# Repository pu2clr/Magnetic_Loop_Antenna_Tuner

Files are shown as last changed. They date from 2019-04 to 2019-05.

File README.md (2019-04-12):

# Magnetic Loop Antenna controlled by Android and Arduino

[Clique aqui para Documentação em Português](https://github.com/pu2clr/Magnetic_Loop_Antenna_Tuner/tree/master/Documentation)

# Table of contents
1. [Folders structure](https://github.com/pu2clr/Magnetic_Loop_Antenna_Tuner#folders-structure)
2. [Source Code](https://github.com/pu2clr/Magnetic_Loop_Antenna_Tuner#source-code) 
3. [Schematic](https://github.com/pu2clr/Magnetic_Loop_Antenna_Tuner#schematic)
    1. [One capacitor version](https://github.com/pu2clr/Magnetic_Loop_Antenna_Tuner#one-capacitor-version)
    2. [Two capacitor version](https://github.com/pu2clr/Magnetic_Loop_Antenna_Tuner#two-capacitors-version)
4. [The Bluetooth shield used with Arduino](https://github.com/pu2clr/Magnetic_Loop_Antenna_Tuner#the-bluetooth-shield-used-with-arduino)
5. [Arduino prototype](https://github.com/pu2clr/Magnetic_Loop_Antenna_Tuner#arduino-circuit-built-on-protoboard)
   1. [One Capacitor version](https://github.com/pu2clr/Magnetic_Loop_Antenna_Tuner#one-capacitor-version-1)
   2. [Two Capacitor version](https://github.com/pu2clr/Magnetic_Loop_Antenna_Tuner#two-capacitors-version-1)
   3. [Arduino with a HM10 (HMSoft) BLE](/sources/ArduinoBLE#arduino-with--a-hm10-hmsoft-ble)
6. [Android Remote Controll Application](https://github.com/pu2clr/Magnetic_Loop_Antenna_Tuner#android-application)
7. [More about the Android Application and Arduino source code](https://github.com/pu2clr/Magnetic_Loop_Antenna_Tuner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)
8. [Messages received by Arduino via Bluetooth](https://github.com/pu2clr/Magnetic_Loop_Antenna_Tuner#messages-received-by-arduino-via-bluetooth)
9. [Videos](https://github.com/pu2clr/Magnetic_Loop_Antenna_Tuner#videos-about-this-project)
10. [Photos](https://github.com/pu2clr/Magnetic_Loop_Antenna_Tuner#photos)

This project is about a minimalist version of a  Remote Control for Magnetic Loop Antenna controlled by Arduino and Android via Bluetooth. I think it can be improved and adjusted for your needs. 

April 3th, 2019.
By PU2CLR,
Ricardo Lima Caratti..

## Folders structure

- [Box_3D_Printer folder](https://github.com/pu2clr/Magnetic_Loop_Antenna_Tuner/tree/master/Box_3D_Printer) is about a box project to use with this project of antenna tuner on Alexloop Magnetic loop antenna or similar. It can be used to build a tuner box by using a 3D printer. [Click here to see a video that shows the box example project with the Android and Arduino Antenna Tuner](https://youtu.be/OKky8gmOWz8).;
- [images folder](https://github.com/pu2clr/Magnetic_Loop_Antenna_Tuner/tree/master/images) has some pictures about this project
- [schematic folder](https://github.com/pu2clr/Magnetic_Loop_Antenna_Tuner/tree/master/schematic) has the schematic document build by [fritzing software](http://fritzing.org/home/), an open-source hardware initiative that allows us to design electronics circuits;
- [sources folder](https://github.com/pu2clr/Magnetic_Loop_Antenna_Tuner/tree/master/sources) has the Android Magnetic Antenna Tunner Application to control the servo attached to a capacitor via bluetooth connection, and the Arduino sketch that implements the contrrol the capacitor (Servo).

## Source code

All Arduino and Android Application codes are avaiable on [Sources folder](https://github.com/pu2clr/Magnetic_Loop_Antenna_Tuner/tree/master/Sources).  __The bluetooth shield have to be desconected during the sketch upload process__. See [ArduinoOneCapacitor.ino][arduino-one-capacitor], [ArduinoTwoCapacitors.ino][arduino-two-capacitor] and [BluetoothTuner.java][bluetooth-tuner] code documentation. You might need change parameters or adapt it for your needs. There is also a version that use a BLE (Bluetooth Low Energy). Click [here](https://github.com/pu2clr/Magnetic_Loop_Antenna_Tuner/tree/master/sources/ArduinoBLE) to see the BLE version.   

## Schematic 

### One capacitor version 

This setup can be used with Alexloop antenna tuner or similar. The tune and fine tune commands are applied to only one capacitor.

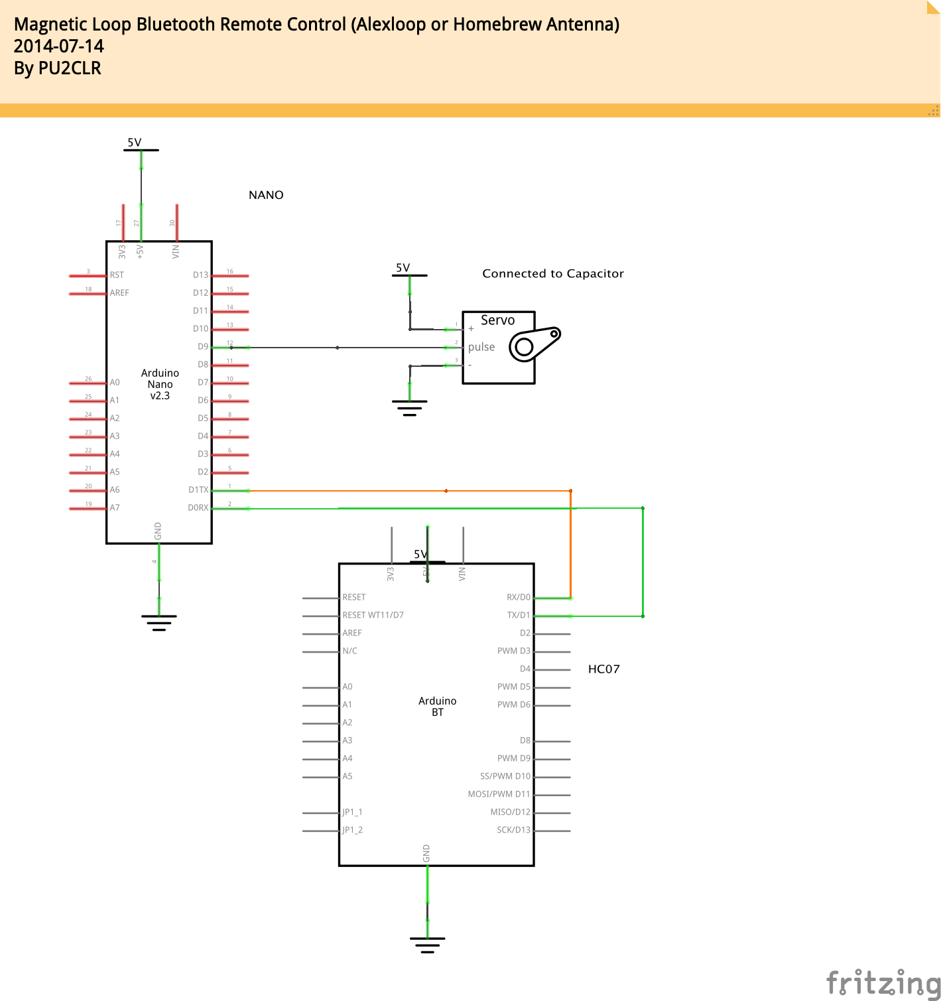
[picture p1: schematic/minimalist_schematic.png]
One capacitor schematic


### Two capacitors version 

This setup uses two servos. The main servo should be attached to a "high" capacitance capacitor. The fine tune servo should be attached to a low capacitance capacitor. This [video](https://youtu.be/w_jXJsiMKIk) shows this idea. 

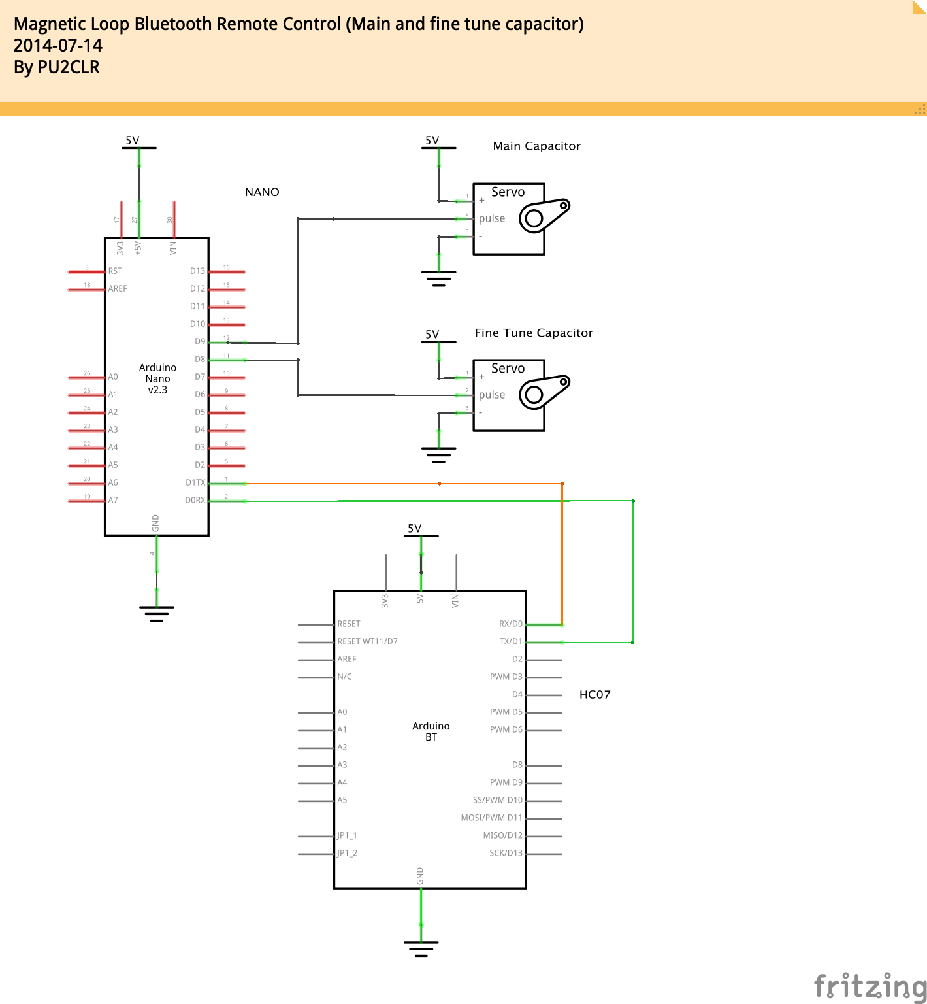
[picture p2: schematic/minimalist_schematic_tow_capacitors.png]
One capacitor schematic


__The same Android Application used to control the One capacitor version can be used to control the two capacitors version.__  There is a checkbox on the Android Application that you can  select one or two capacitors setup. 

__IMPORTANT__:
It is recommended that you check your servo parameters (specifications). You might need change some defined constants on Android Application and Arduino sketch. You will find documentation on [ArduinoOneCapacitor.ino][arduino-one-capacitor], [ArduinoTwoCapacitors.ino][arduino-two-capacitor] and [BluetoothTuner.java][bluetooth-tuner] to do that if necessary.   

## The Bluetooth shield used with Arduino

You can use the HC-05 or HC-07 bluetooth shield. I did not get success with BLE standard and the Android Application developed for this project. 

### Bluetooth HC-05 - Photo 1

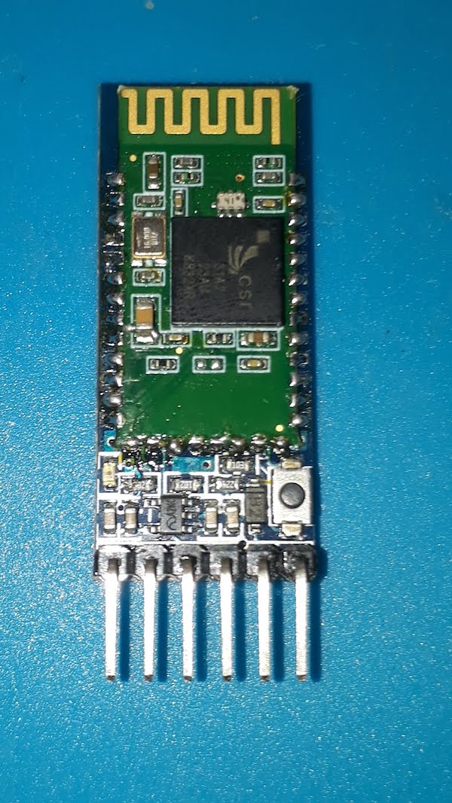
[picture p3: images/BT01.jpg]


### Bluetooth HC-05 - Photo 2

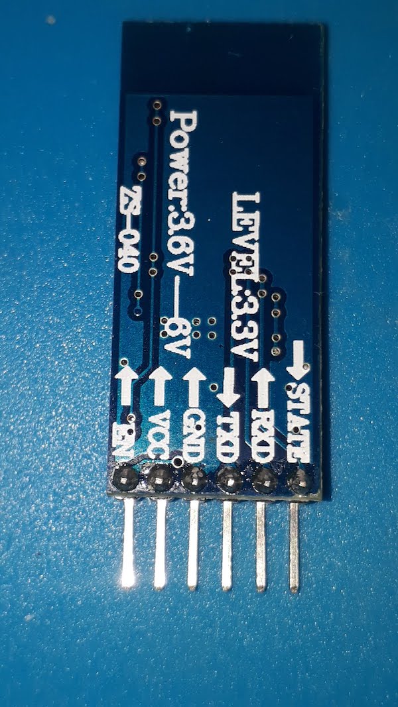
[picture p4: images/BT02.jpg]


### Arduino circuit built on protoboard

#### One Capacitor version

The photo below shows the Android, Bluetooth and Servo setup for one capacitor version. Please, check your Servo specification. You might need to change some definition on the Arduino sketch. See [ArduinoOneCapacitor.ino][arduino-one-capacitor] sketch source code documentation.    

Android Remote Control

#### Two Capacitors version

The photo below shows the Android, Bluetooth and two Servos setup for two capacitors. The fine tune capacitor should have low capacitance. Please, check your Servo specification. You might need to change some definitions on the Arduino sketch. See [ArduinoTwoCapacitor.ino][arduino-two-capacitor] sketch source code documentation.    

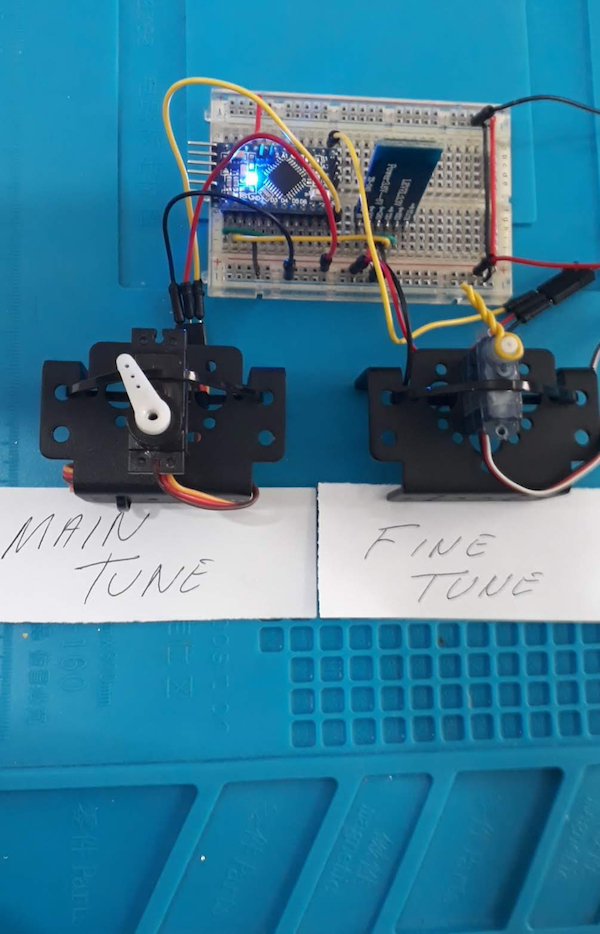
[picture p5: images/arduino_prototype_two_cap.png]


### Android Application 

The version of Android Application used here was built in 2014. The last Android Studio used to build it was 3.3.2 (2019). Probable, you will need to do some adjust on your IDE environment to build this application.

You also might need to check your servo specification and change the [BluetoothTuner.java][bluetooth-tuner] (see comments in the java program). 

#### Android Remote Controll - Photo 1

Connecting to Bluetooth you should press the Bluetooth button and select the paired Bluetooth, in this case it is HC07.  You have to pair the bluetooth before by using system interface. 

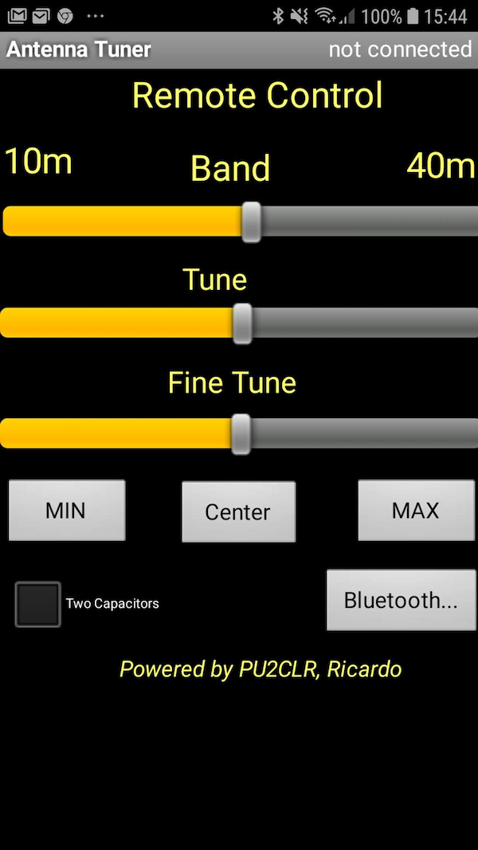
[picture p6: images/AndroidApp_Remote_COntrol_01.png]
Android Remote Control


#### Android Remote Controll - Photo 2

Selecting the paired bluetotth. 

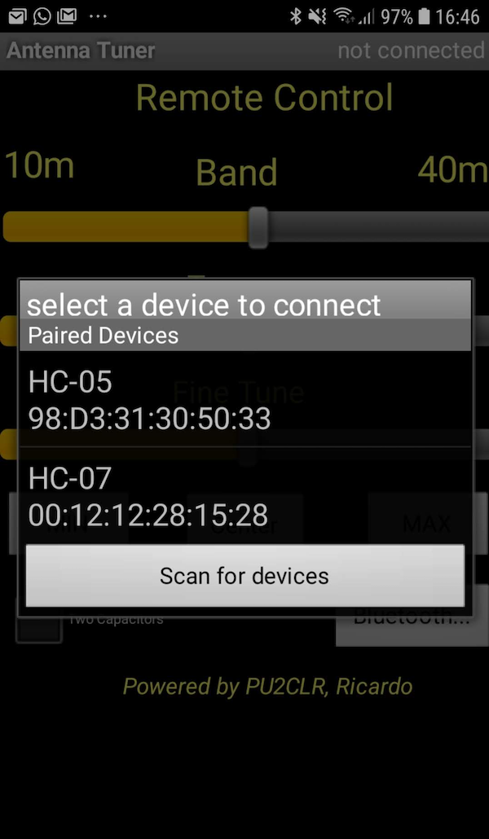
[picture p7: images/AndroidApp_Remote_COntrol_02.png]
Android Remote Control


#### Android Remote Controll - Photo 3

Bluetooth paired and ready to send commands to Arduino circuit.

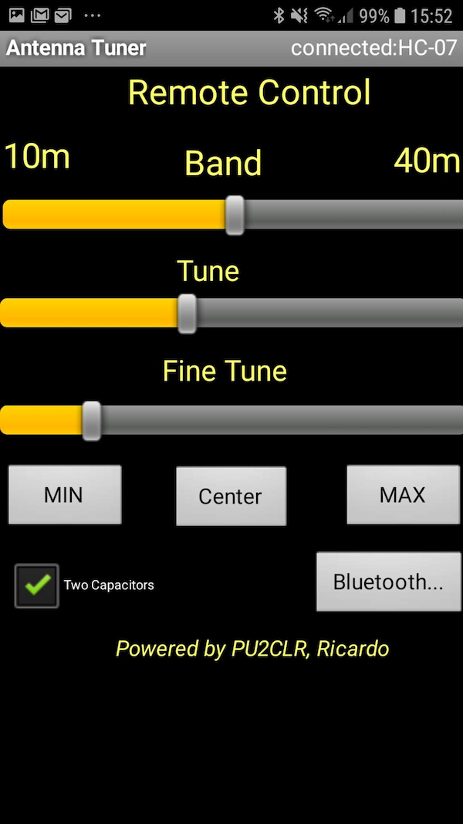
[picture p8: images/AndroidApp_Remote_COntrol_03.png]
Android Remote Control


## More about the Android Application and Arduino source code

All source code can be found [here](https://github.com/pu2clr/Magnetic_Loop_Antenna_Tuner/tree/master/Sources).  You might need to change some configurations depending on servo specification and kind of capacitor you are using. The Arduino and Android Application source code are docummented as shown below.

### Important parts of the Arduino and Android code

The pieces of code below illustrate the configuration on Android Application (Java) and Arduino (C / C ++) that can be adjusted by you according your servo and capacitor specification.

#### Aplicativo Android (BluetoothTuner.java)

```java
    // You might change this setup depending on your servo specification
    public int OFFSET = 800;   // Min. Pisition  (0 degree)
    public int MAXPOS = 2200;  // Max. position  (Max. degrre)
    public int CENTER = (MAXPOS - OFFSET)/2 + OFFSET /2;   // Center is CENTER + OFFSET
```

```java 
    // Change parameters for one or two capacitors
    // You might change the values depending on your capacitance of your capacitor and servo specification
    public void onTwoCapacitorsClicked(View v) {

        boolean chk =((CheckBox) v).isChecked();
        if (chk ) { //
            MIDDLE_MAX_OFFSET = MAXPOS;
            MIDDLE_CENTER = CENTER;
            FINE_MAX_OFFSET = MAXPOS / 4;
            FINE_CENTER = CENTER / 4;
        } else {    // One Capacitor estimated values. You might need change it
            MIDDLE_MAX_OFFSET = MAXPOS / 4;
            MIDDLE_CENTER = CENTER / 4;
            FINE_MAX_OFFSET = MAXPOS / 8;
            FINE_CENTER = CENTER / 8;
        }

        seekbarMiddleTune.setMax(MIDDLE_MAX_OFFSET);
        seekbarMiddleTune.setProgress(MIDDLE_CENTER);

        seekbarFineTune.setMax(FINE_MAX_OFFSET);
        seekbarFineTune.setProgress(FINE_CENTER);

    }
```    

#### Arduino Sketch

```cpp
// Define pulse width modulation for fine, regular and large tune 
#define FINE_TUNE            5            // short pulse on servo
#define NORMAL_TUNE          15           // regular pulse on servo
#define LARGE_TUNE           50           // large pulse on servo

#define SERVO_PIN            9            // Pin where is connected the servo
#define CAP_LED_PIN         13            // Define the status LED pin of the capacitor

#define MIN_PULSE          800          // Min. pulse of the servo (you need to know abour you servo specification)
#define MAX_PULSE         2200          // Max. pulse of the servo (you need to know abour you servo specification)
```

## Messages received by Arduino via Bluetooth

The Arduino receives a message sent by the Android Application or any terminal bluetooth application connect to the Arduino, and proceess this message by sending pulse to the servo attached to the capacitor.  

See on the Arduino sketch (ArduinoOneCapacitor.ino and ArduinoTwoCapacitors.ino), the defined constants FINE_TUNE, NORMAL_TUNE, LARGE_TUNE, MIN_PULSE and MAX_PULSE.  These constants define the pulse width modulation for the servo. You might need to change the values of these constants depending on the servo specification. 

#### Commands received by Arduino via Bluetooth and actions

After the Bluetooth connection is established between Arduino and Android Application, the Arduino start waiting for a message from the remote control. The table below shows the messeges processed by Arduino. 

| Character | Description |
| --- | --- |
| + | Fine tune clockwise (short pulse width modulation). |
| - | Fine tune counter-clockwise (short pulse width modulation). |
| r | Regular tune clockwise (midle pulse width modulation). |
| l | Regular tune counter-clockwise (midle pulse width modulation). |
| R | Large tune clockwise (large pulse width modulation). |
| L | Large tune counter-clockwise (large pulse width modulation). |
| M | The servo goes to the maximum position. |
| m | The servo goes to the minimum position. |
| C or c | The servo goes to central position. |
| F | This means that the servo should go to a certain position. This message is followed by a numeric value (servo position) and the '#' character indicating  the end of the message. Example: The mensagem F1000# makes the servo go to position 1000. | 
| T | Like 'F' this means that the servo should go to a certain position. Example: The mensagem T1500# makes the servo go to position 1500.|

##### IMPORTANT 

The files  [ArduinoOneCapacitor.ino][arduino-one-capacitor], [ArduinoTwoCapacitors.ino][arduino-two-capacitor] and [BluetoothTuner.java][bluetooth-tuner] will help you understand the Antenna Tuner comunication protocol. 

## Photos

### Photo 1 

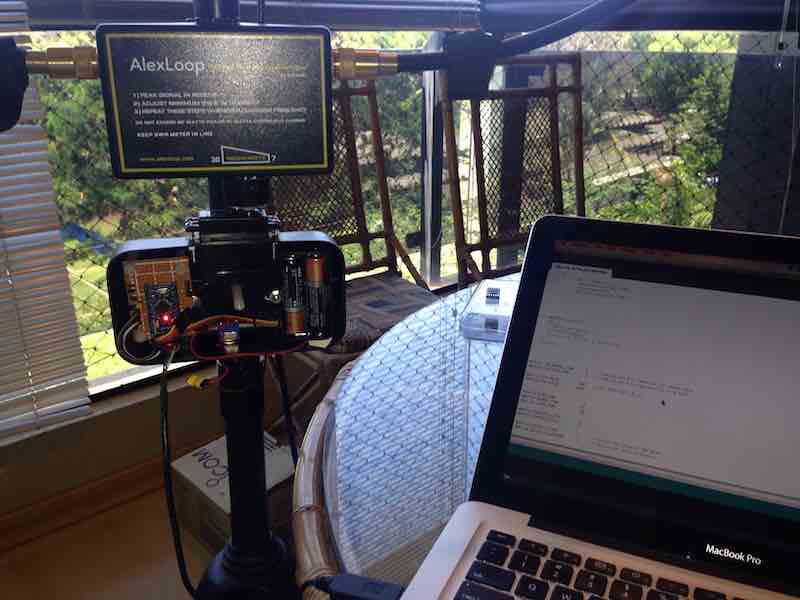
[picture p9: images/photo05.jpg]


### Foto 2

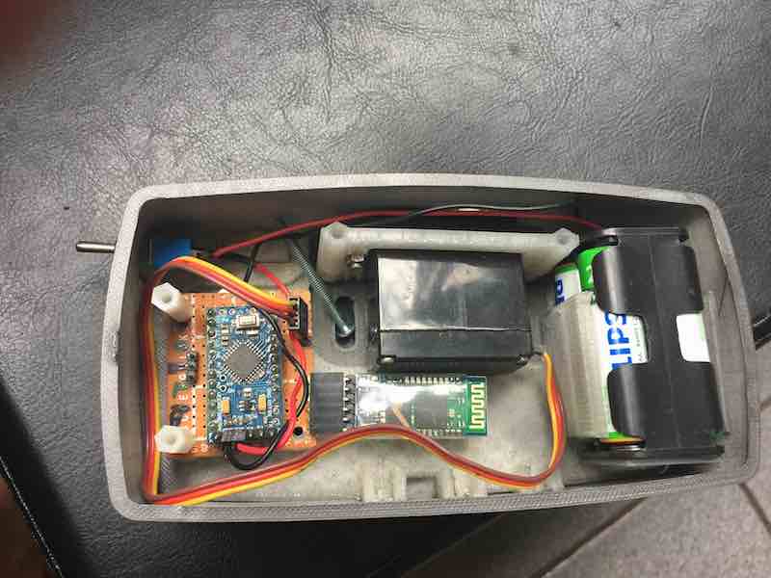
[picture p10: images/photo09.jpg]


### Foto 3

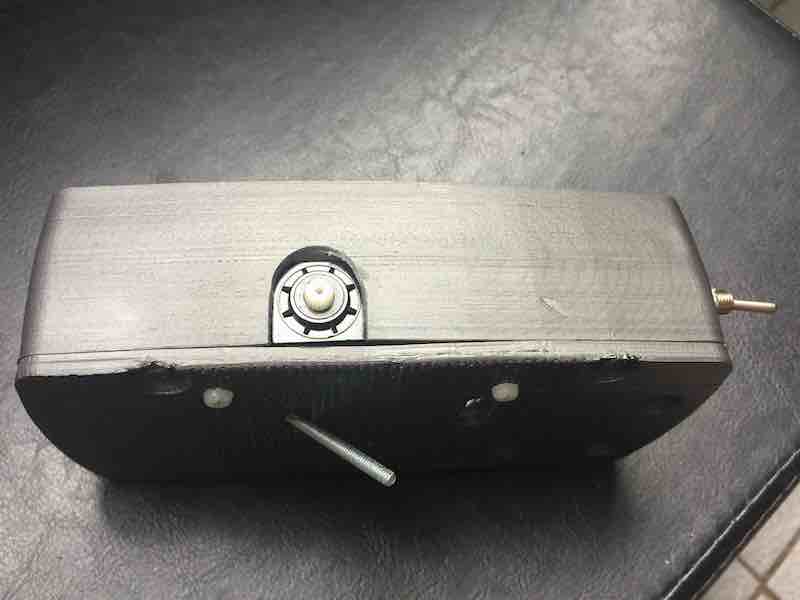
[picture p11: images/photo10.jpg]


## References

- [Arduino](https://www.arduino.cc)
- [App Inventor](http://appinventor.mit.edu/explore/index-2.html)
- [Bluetooth HC-05 specification](https://electrosome.com/hc-05-serial-bluetooth-module/)

## Videos about this project
- [A version of this project working (Youtube Video)](https://youtu.be/PbnP8gIDb78)
- [Remote Tuner for Alexloop (Part I)](https://youtu.be/ZKfOUCcYrz8)
- [Remote Tuner for Alexloop (Part II)](https://youtu.be/PbnP8gIDb78)
- [Antenna Tuner with two capacitors controlled by Arduino](https://youtu.be/Rwl3G2ET7Jw)
- [Antenna Tuner with two capacitors controlled by Arduino - Part II](https://youtu.be/hfnlE1sbnEk)
- [New Android Interface for Antenna Tuner](https://youtu.be/w_jXJsiMKIk)

[//]: References

[arduino-one-capacitor]: <https://github.com/pu2clr/Magnetic_Loop_Antenna_Tuner/blob/master/sources/ArduinoOneCapacitor/ArduinoOneCapacitor.ino>

[arduino-two-capacitor]: <https://github.com/pu2clr/Magnetic_Loop_Antenna_Tuner/blob/master/sources/ArduinoTwoCapacitors/ArduinoTwoCapacitors.ino>

[bluetooth-tuner]: <https://github.com/pu2clr/Magnetic_Loop_Antenna_Tuner/blob/master/sources/AndroidApplication/app/src/main/java/br/eti/caratti/AntennaTuner/BluetoothTuner.java>

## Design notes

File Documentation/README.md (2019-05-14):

# Antena Loop Magnética controlada por SmartPhone Android e Arduino 

# Sumário

1. [Introdução](/Documentation#introdução)
2. [Estrutura de pastas e arquivos](/Documentation#estrutura-de-pastas-e-arquivos)
3. [Como baixar os arquivos deste projeto (Download)](/Documentation#como-baixar-os-arquivos-deste-projeto-download)
4. [Trechos de código sensíveis ao tipo de servo utilizado](/Documentation#trechos-de-código-sens%C3%ADveis-ao-tipo-de-servo-utilizado)
5. [Esquema](/Documentation#esquema-elétrico)
   1. [Com um capacitor](/Documentation#versão-com-um-capacitor)
   2. [Com dois capacitores](/Documentation#versão-com-dois-capacitores)
6. [Dispositivo Bluetooth utilizado neste projeto](/Documentation#dispositivo-bluetooth-utilizado-neste-projeto)
8. [Protótipo Arduino](/Documentation#protótipo-arduino)
   1. [Bluetooth Clássico x BLE](/Documentation#bluetooth-clássico-x-ble)
   2. [Versão com um capacitor (Bluetooth Clássico)](/Documentation#versão-com-um-capacitor)
   3. [Versão com dois capacitores (Bluetooth Clássico)](/Documentation#versão-com-dois-capacitores-1)
7. [Aplicativo Android](/Documentation#aplicativo-android) 
8.  [Código-fonte](/Documentation#código-fonte) 
9. [Protocolo de mensagem (Spartphone e Arduino via Bluetooth)](/Documentation#protocolo-de-mensagem-spartphone-e-arduino-via-bluetooth)
10. [Fotos](/Documentation#fotos)
11. [Videos](https://github.com/pu2clr/Magnetic_Loop_Antenna_Tuner#videos-about-this-project)

## Introdução 

Este projeto é uma versão básica de um Sintonizador de Antenas implementado com Arduino e controlado por um dispositivo móvel baseado em Android. Com este projeto, será possível controlar remotamente, por exemplo, uma Antena Loop Magnética no estilo da [Alexloop](http://www.alexloop.com/index.html) ou uma de construção caseira, via Bluetooth, a partir do seu dispositivo móvel (celular ou tablet) baseado em Android. Há duas opções preferencialmente sugeridas neste documento: uma utilizando o sintonizador de antenas com um capacitor e outra com dois capacitores. Essas duas versões utilizam o Bluetooth Clássico (HC-05, HC-07 etc). __Há também uma versão experimental do sintonizador de antenas utilizando um Bluetooth Low Energy (BLE). No entanto, até o presente momento o aplicativo para celular ainda não foi desenvolvido ou adaptado para esta versão com o BLE__. Assista aos vídeos referenciados no final desta página. Acredito que este projeto possa oferecer os elementos básicos para projetos mais robustos envolvendo as tecnologias utilizadas aqui. 

Fortaleza, 3 de abril de 2019.
Por PU2CLR,
Ricardo Lima Caratti.

## Estrutura de pastas e arquivos

Este trabalho está organizado em pastas. Cada pasta possui o conteúdo descrito a seguir: 

- A pasta [Box_3D_Printer](https://github.com/pu2clr/Magnetic_Loop_Antenna_Tuner/tree/master/Box_3D_Printer) contem o projeto de uma caixa construída em uma impressora 3D especialmente para a [Alexloop][alex-loop] ou similar. [Clique aqui](https://youtu.be/OKky8gmOWz8) para assistir a um vídeo sobre este projeto;
- A pasta [images](https://github.com/pu2clr/Magnetic_Loop_Antenna_Tuner/tree/master/images) contém fotos sobre este projeto;
- A pasta [schematic](https://github.com/pu2clr/Magnetic_Loop_Antenna_Tuner/tree/master/schematic) contém dois esquemas construídos por meio do software  [fritzing](http://fritzing.org/home/), um programa livre para construção de esquemas elétricos. Há duas versões do projeto: uma utilizando um Servo para trabalhar somente com um capacitor; e outra utilizando dois servos para trabalhar com um capacitor principal e outro de sintonia fina;
- A pasta [sources](https://github.com/pu2clr/Magnetic_Loop_Antenna_Tuner/tree/master/sources) contém os códigos-fonte do Aplicativo para SmartPhone para Android,  e dois sketchs (programas para Arduino).  

## Como baixar os arquivos deste projeto (Download)

A estrutura de pastas e arquivos descrita no item anterior é apresentada neste repositório de projetos conforme ilustra a figura a seguir. Clique [aqui](https://github.com/pu2clr/Magnetic_Loop_Antenna_Tuner.git) para entrar na página  e em seguida clique no botão verde, à direita,  identificado por "Clone or Download". 

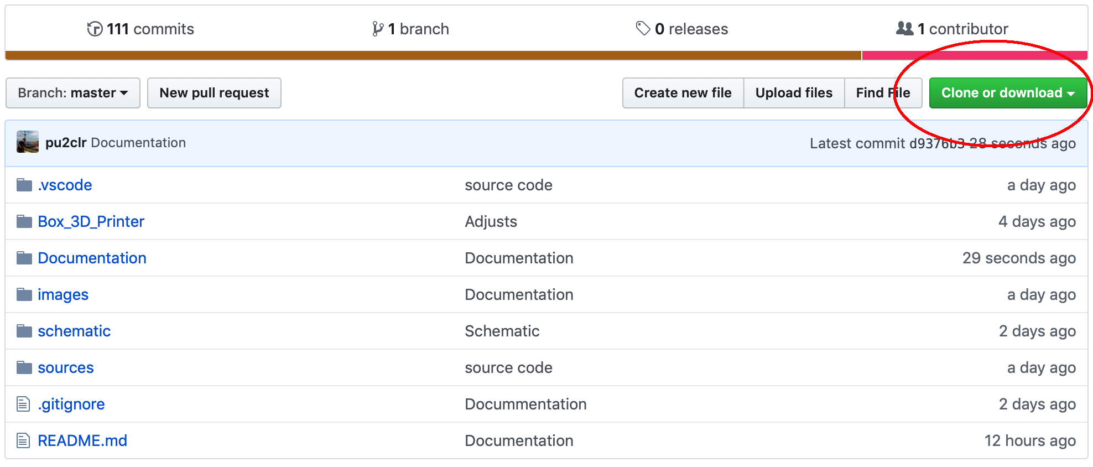
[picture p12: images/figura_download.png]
Página para Download do projeto (https://github.com/pu2clr/Magnetic_Loop_Antenna_Tuner.git/)


## Esquema elétrico

Há duas versões do sintonizador de antena. Uma com um capacitor e outra com dois capacitores. A opção com dois capacitores sugere que o capacitor de sintonia fina seja de baixa capacitância. Dessa forma, o processo de sintonia ficará mais fácil e mais preciso. [Clique aqui](https://youtu.be/w_jXJsiMKIk) para assistir a um vídeo que ilustra o sintonizador com dois capacitores.  

### Versão com um capacitor 

O esquema a seguir ilustra a versão do sintonizador de antena configurado para somente um capacitor acoplado a um servo. Esta versão se aplica para antenas no estilo da [Alexloop][alex-loop] ou loop magnética de construção caseira que utiliza capacitores variáveis com duas ou mais seções.  

One capacitor schematic

### Versão com dois capacitores 

O esquema a segui apresenta a versão do sintonizador com dois capacitores acoplados em dois servos.

One capacitor schematic

### Dispositivo Bluetooth utilizado neste projeto

Os dispositivos HC-05 e HC-06 e HC07 funcionaram com sucesso. A versão utilizando um Bluetooth BLE pode ser vista clicando [aqui](/sources/ArduinoBLE). As figuras a seguir apresentam um bluetooth clássico (HC-05). 

#### Bluetooth Clássico HC-05 - Foto 1
Android Remote Control

#### Bluetooth Clássico HC-05 - Foto 2

Android Remote Control

## Protótipo Arduino

Este projeto apresenta basicamente três opções para a construção de um Sintonizador de Antenas Loop Magnética controlado por Arduino e  Smartphone. A primeira opção propõe a utilização de um capacitor acoplado a um Servo conectado ao Arduino que, por sua vez, interage com um dispositivo Bluetooth clássico (HC-05, HC-07 ou similar). A segunda opção propõe a utilização de dois capacitores, um para sintonia normal e outro para sintonia fina, que operam de forma similar à versão anterior usando um Bluetooth clássico. A terceira opção utiliza praticamente a mesma configuração da primeira opção, exceto que no lugar do Bluetooth Clássico, é utilizado um BLE (HM10 / HMSoft). Os códigos para cada opção descrita anteriormente estão disponíveis na pasta [sources deste repositório](https://github.com/pu2clr/Magnetic_Loop_Antenna_Tuner/tree/master/sources).

As duas primeiras opção funcionam perfeitamente em dispositivos móveis Android (Celular ou Tablet) por meio do [Aplicativo Android](/Documentation#aplicativo-android) desenvolvido para este projeto. Isto é, com o mesmo Aplicativo Android, é possível controlar um sintonizador de antena loop magnética com um ou dois capacitores usando o __Bluetooth Clássico__.

A terceira opção deste projeto implementa a comunicação do Arduino com BLE. No entanto, até o momento em que escrevo estas linhas, ainda não desenvolvi um programa específico para controlar remotamente o sintonizador de antenas via BLE. É possível porém, utilizar um Aplicativo qualquer de comunicação serial para este fim. Clique [aqui](https://github.com/pu2clr/Magnetic_Loop_Antenna_Tuner/tree/master/sources/ArduinoBLE) para mais detalhes sobre como controlar o sintonizador de antenas loop magnética usando BLE. 

### Bluetooth Clássico x BLE

Inicialmente, o sintonizador remoto para antena loop magnética usando Smartphone via Bluetooth, foi projetado para funcionar com  dispositivos Bluetooth clássicos do tipo HC-05, HC-7 etc. No entanto, nos últimos 5 anos, a oferta de dispositivos Bluetooth com a especificação BLE (Bluetooth Low Energy) para plataformas de desenvolvimento como Arduino aumentou sobremaneira. Além disso, o custo destes dispositivos Bluetooth ficou bastante atrativo. Seguem algumas considerações e experiências sobre os dois tipos de Bluetooth observadas durante o desenvolvimento deste projeto:

- O Bluetooth Clássico oferece uma documentação mais rica e com mais exemplos e experiências de uso em projetos com Arduino
- Os dispositivos Bluetooth clássicos ainda são mais baratos e mais fáceis de serem adquiridos; 
- BLE permite conexão com dispositivos móveis da linha Apple. Com isso, é possível desenvolver ou obter um aplicativo de terceiro para iOS que possa ser utilizado com o sintonizador de antenas proposto neste projeto;
- Ainda que seja possível utilizar este projeto em ambiente iOS via BLE, o Bluetooth não aparece na lista padrão de dispositivos pareados do sistema da Apple. Ou seja, o BLE só é visualizado durante a execução do Aplicativo utilizado como controle remoto. Este comportamento pode confundir o usuário em sua primeira análise;
- Em dispositivos do tipo Android, o BLE funciona quase da mesma forma que o Bluetooth Clássico. Isto é, não há diferença visível para o usuário final entre o modelo clássico e o BLE. 
- No que tange à codificação de programas usando Bluetooth Clássico e BLE, tanto programa Arduino (sketch) como o programa para dispositivos móveis Android e iOS utilizam abordagens diferentes. Isto é, uma vez selecionado o tipo de Bluetooth que será utilizado, o código desenvolvido deve utilizar as blbliotecas e APIs (Application Program Interface) contruídas para o Bluetooth escolhido.   

## Propostas para construção do sintonizador de Antenas Controlado por Arduino e Smartphone

### Versão com um Capacitor

A foto a seguir mostra a configuração do  Android, Bluetooth __Clássico (HC-05, HC-07 etc)__ e Servo. É recomendável que você verifique as especificações do servo que você estiver utilizado. É possível que você necessite alterar  algumas definições do servo no sketch.  Tente acompanhar a documentação existente no próprio sketch.

Android Remote Control

### Versão com dois capacitores

A foto a seguir apresenta a montagem da versão do protótipo utilizando dois servos que serão acoplados a dois capacitores. 
O sketch [ArduinoTwoCapacitor.ino][arduino-two-capacitor] implementa este versão.    

Android Remote Control

## Aplicativo Android

A aplicação para dispositivo Android foi desenvolvido em 2014 utilizando os recursos nativos do ambiente de desenvolvimento para Android (conhecido atualmente como Android Studio). A última compilação deste aplicativo foi em 2019 utilizando o [Android Studio 3.3.2.](https://developer.android.com/studio/). O programa está bem documentado e poderá ajudá-lo a entender como foi feita a comunicação de um dispositivo Android com o Arduino via Bluetooth Clássico. O módulo principal do aplicativo é o [BluetoothTuner.java][bluetooth-tuner].  Baixe e instale o [Android Studio](https://developer.android.com/studio/) e __siga as orientações do ambiente de desenvolvimento Android para abrir, compilar e instalar o aplicativo no seu dispositivo móvel__. 

Atualmente há outros ambientes de desenvolvimento para Android mais fácies de utilizar e desenvolver esse tipo de aplicativo. Recomendo fortemente a utilização do [MIT App Inventor](http://appinventor.mit.edu/explore/index-2.html). Veja também outros ambientes de desenvolvimento multiplataforma como [Apache Cordova](https://cordova.apache.org) e [Ionic](https://ionicframework.com). 

### Foto 1

A figura a seguir ilustra a primeira tela do aplicativo. Você precisará parear o Bluetooth previamente em seu dispositivo móvel (celular ou tablet). 

Android Remote Control

### Foto 2

Na lista de dispositivos Bluetooth pareados, selecione o Bluetooth conectado ao Arduino (foi usando nos testes o HC-05, HC-06 e HC-07). 

Android Remote Control

### Foto 3

Uma vez conectado o Bluetooth com sucesso, o Aplicativo pode ser utilizado para enviar comandos para o Arduino.

Android Remote Control

### Código-fonte

Todos os fontes utilizados neste projeto estão disponíveis na [pasta 'sources'](https://github.com/pu2clr/Magnetic_Loop_Antenna_Tuner/tree/master/Sources).  __Durante o upload do sketch para o Arduino, você deve desconectar o Bluetooth do arduino__. É recomendável acompanhar a documentação escrita no programa.

Dependendo da configuração que você optar, um ou dois capacitores, bem como as especificações técnicas do servo que você utiliza, é possível que você precise modificar alguns parâmetros no sketch do Arduino e também no Aplicativo Android. 
Veja a documentação nos fontes [ArduinoOneCapacitor.ino][arduino-one-capacitor], [ArduinoTwoCapacitors.ino][arduino-two-capacitor] e [BluetoothTuner.java][bluetooth-tuner]. 

### Trechos de código sensíveis ao tipo de servo utilizado

Os trechos de código a seguir ilustram a configuração no Aplicativo Android  (em Java) e Arduino (em C/C++) que permitem um ajuste fino do servo e capacitor utilizado por você. Caso não conheça os valores especificados pelo seu servo, inicie seus testes sem fazer alteração nos códigos

#### Trechos no Aplicativo Android (BluetoothTuner.java)

É nenessário um conhecimento mínimo em desenvolvimento de aplictivos para Android para elaborar algumas mudanças no Aplicativo. Caso você não se sinta seguro para fazer isso, é melhor iniciar os experimentos sem fazer alteração alguma. 

O código a seguir define os limites máximo (MAXPOS) e mínimo (OFFSET), bem como a posição central (CENTER) do servo no Aplicativo Android ([BluetoothTuner.java][bluetooth-tuner]). Os componentes de interface do aplicativo __SeekBar__ (barras Band, Tune e Fine Tune) utilizam estes valores como referência para enviar valores entre os limites (MAXPOS e OFFSET) para o servo na proporção que o usuário do aplicativo arrasta o dedo sobre os componentes de interface. 

```java
    // You might change this setup depending of your servo specification
    public int OFFSET = 800;   // Min. Pisition  (0 degree)
    public int MAXPOS = 2200;  // Max. position  (Max. degrre)
    public int CENTER = (MAXPOS - OFFSET)/2 + OFFSET /2;   // Center is CENTER + OFFSET
```

O código a seguir configura a sintonia fina (Tune e Fine Tune) e usa como referência as constantes descritas anteriormente. Note também que, dependendo da configuração selecionada (um ou dois capacitores), os valores para componentes de sintonia fina mudam. É possível que você encontre valores mais adequados para o seu tipo de servo e capacitância do seu capacitor.

```java 
    // Change parameters for one or two capacitors
    // You might change the values depending of your capacitance of your capacitor and servo specification
    public void onTwoCapacitorsClicked(View v) {

        boolean chk =((CheckBox) v).isChecked();
        if (chk ) { //
            MIDDLE_MAX_OFFSET = MAXPOS;
            MIDDLE_CENTER = CENTER;
            FINE_MAX_OFFSET = MAXPOS / 4;
            FINE_CENTER = CENTER / 4;
        } else {    // One Capacitor estimated values. You might need change it
            MIDDLE_MAX_OFFSET = MAXPOS / 4;
            MIDDLE_CENTER = CENTER / 4;
            FINE_MAX_OFFSET = MAXPOS / 8;
            FINE_CENTER = CENTER / 8;
        }

        seekbarMiddleTune.setMax(MIDDLE_MAX_OFFSET);
        seekbarMiddleTune.setProgress(MIDDLE_CENTER);

        seekbarFineTune.setMax(FINE_MAX_OFFSET);
        seekbarFineTune.setProgress(FINE_CENTER);

    }
```    

#### Trechos no sketch (Android)

O código a seguir definem os valores máximos (MAX_PULSE) e mínimos (MIN_PULSE) dos servos no programa Arduino. Também define as constantes de sintonia fina (FINE_TUNE), sintonia (NORMAL_TUNE) e banda (LARGE_TUNE) que __não__ são utilizadas no caso do aplicativo Android. O Aplicativo Android já envia o valor exato da posição do servo.

```cpp
// Define pulse width modulation for fine, regular and large tune 
#define FINE_TUNE            5            // short pulse on servo
#define NORMAL_TUNE          15           // regular pulse on servo
#define LARGE_TUNE           50           // large pulse on servo

#define SERVO_PIN            9            // Pin where is connected the servo
#define CAP_LED_PIN         13            // Define the status LED pin of the capacitor

#define MIN_PULSE          800          // Min. pulse of the servo (you need to know abour you servo specification)
#define MAX_PULSE         2200          // Max. pulse of the servo (you need to know abour you servo specification)
```

## Protocolo de mensagem (Spartphone e Arduino via Bluetooth)

O Arduino recebe as mensagens enviadas pelo Aplicativo Android via conexão [UART](https://paginas.fe.up.pt/~hsm/docencia/comp/uart/). Qualquer programa que utiliza Bluetooth e for capaz de enviar sequências de caracteres poderá ser utilizado. A tabela a seguir apresenta os comandos (mensagens) e as ações executadas pelo Arduino.   

Para mais informações, veja no sketch Arduino ([ArduinoOneCapacitor.ino][arduino-one-capacitor] ou [ArduinoTwoCapacitors.ino][arduino-two-capacitor]), as constantes definidas FINE_TUNE, NORMAL_TUNE, LARGE_TUNE, MIN_PULSE and MAX_PULSE.  Estas constantes definem a largura de pulso para rodar o servo vendidos. Embora a maioria dos servos encontrados no comércio utilizem especificações similares, é possível que você precise modificar os valores para adequar melhor ao seu servo. O condigo-fonte [BluetoothTuner.java][bluetooth-tuner] (do aplicativo Android) também pode precisar de ajustes dependendo do seu servo. 

### Tabela de comandos recebidos pelo Arduino via Bluetooth

| Mensagem | Descrição |
| --- | --- |
| + | Sintonia fina no sentido horário. |
| - | Sintonia fina no sentido anti-horário. |
| r | Sintonia média no sentido horário. |
| l | Sintonia média no sentido anti-horário. |
| R | Sintonia larga no sentido horário. |
| L | Sintonia larga no sentido anti-horário. |
| M | Faz com que o servo ou servos girem até a posição máxima. |
| m | Faz com que o servo  ou servos girem até a posição mínima. |
| C or c | Posiciona o servo ou servos no centro. |
| F | Esta mensagem vem composta com número e conduz o servo para uma posição específica. Exemplo: a mensagem F1000# faz com que o servo vá para a posição 1000. O caractere # indica o fim da mensagem para este caso. | 
| T | Como descrito em  anteriormente ('F') este mensagem conduz o servo para ir para uma dada posição. Exemplo: a mensagem  T1500# faz com que o servo vá para a posição 1500.|

#### IMPORTANTE 

Os arquivos (código-fonte) [ArduinoOneCapacitor.ino][arduino-one-capacitor], [ArduinoTwoCapacitors.ino][arduino-two-capacitor] and [BluetoothTuner.java][bluetooth-tuner] poderão ser úteis para o entendimento deste protocolo de comunicação.

# Fotos

### Foto 4

Android Remote Control

### Foto 5

Android Remote Control

### Foto 6

Android Remote Control

## Referências

- [Arduino](https://www.arduino.cc)
- [App Inventor](http://appinventor.mit.edu/explore/index-2.html)
- [Bluetooth HC-05 specification](https://electrosome.com/hc-05-serial-bluetooth-module/)

## Vídeos

- [Sobre a versão deste projeto no Youtube](https://youtu.be/PbnP8gIDb78)
- [Remote Tuner for Alexloop (Part I)](https://youtu.be/ZKfOUCcYrz8)
- [Remote Tuner for Alexloop (Part II)](https://youtu.be/PbnP8gIDb78)
- [Antenna Tuner with two capacitors controlled by Arduino](https://youtu.be/Rwl3G2ET7Jw)
- [Antenna Tuner with two capacitors controlled by Arduino - Part II](https://youtu.be/hfnlE1sbnEk)
- [New Android Interface for Antenna Tuner](https://youtu.be/w_jXJsiMKIk)

[//]: References

[arduino-one-capacitor]: <https://github.com/pu2clr/Magnetic_Loop_Antenna_Tuner/blob/master/sources/ArduinoOneCapacitor/ArduinoOneCapacitor.ino>

[arduino-two-capacitor]: <https://github.com/pu2clr/Magnetic_Loop_Antenna_Tuner/blob/master/sources/ArduinoTwoCapacitors/ArduinoTwoCapacitors.ino>

[bluetooth-tuner]: <https://github.com/pu2clr/Magnetic_Loop_Antenna_Tuner/blob/master/sources/AndroidApplication/app/src/main/java/br/eti/caratti/AntennaTuner/BluetoothTuner.java>

[alex-loop]: <http://www.alexloop.com>

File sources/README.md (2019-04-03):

#  Arduino and Android Application codes

All Arduino and Android Application codes are avaiable here.  

## Android Application

If you want to use the Android Application without any modification, you can install the binary located at __AndroidApplication/app/build/outputs/apk/debug/__ folder ([click here to download the apk](https://github.com/pu2clr/Magnetic_Loop_Antenna_Tuner/blob/master/sources/AndroidApplication/app/build/outputs/apk/debug/app-debug.apk)).  However, it is recomended to use the [Android Studio](https://developer.android.com/studio) to modify, build and deploy the aplication.

## Arduino Sketch

The [ArduinoOneCapacitor folder](https://github.com/pu2clr/Magnetic_Loop_Antenna_Tuner/tree/master/sources/ArduinoOneCapacitor) has the [Arduino sketch](https://github.com/pu2clr/Magnetic_Loop_Antenna_Tuner/blob/master/sources/ArduinoOneCapacitor/ArduinoOneCapacitor.ino). 

The sketch is documented and can help you to understand the protocol used to communicate with Android Device. Please, Dropout (disconnect) the Bluetooth from Arduino to upload this sketch to Arduino. After upload, connect again the Bluetooth to Arduino. 

__The bluetooth shield have to be desconected during the sketch upload process__. 

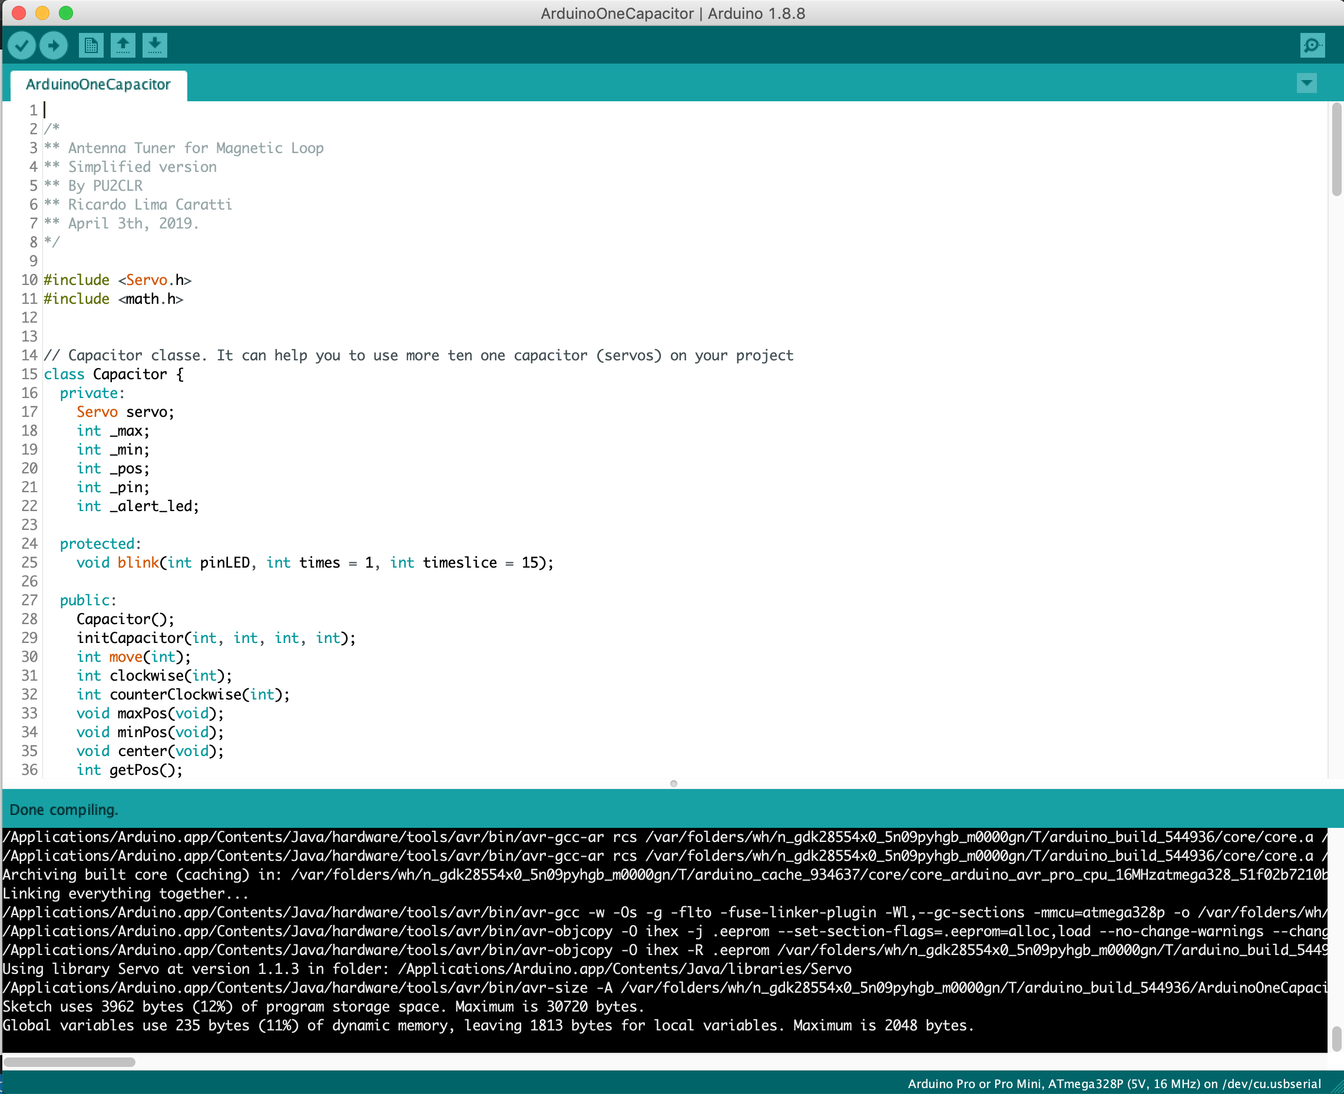
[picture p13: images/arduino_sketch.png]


## Android Studio 

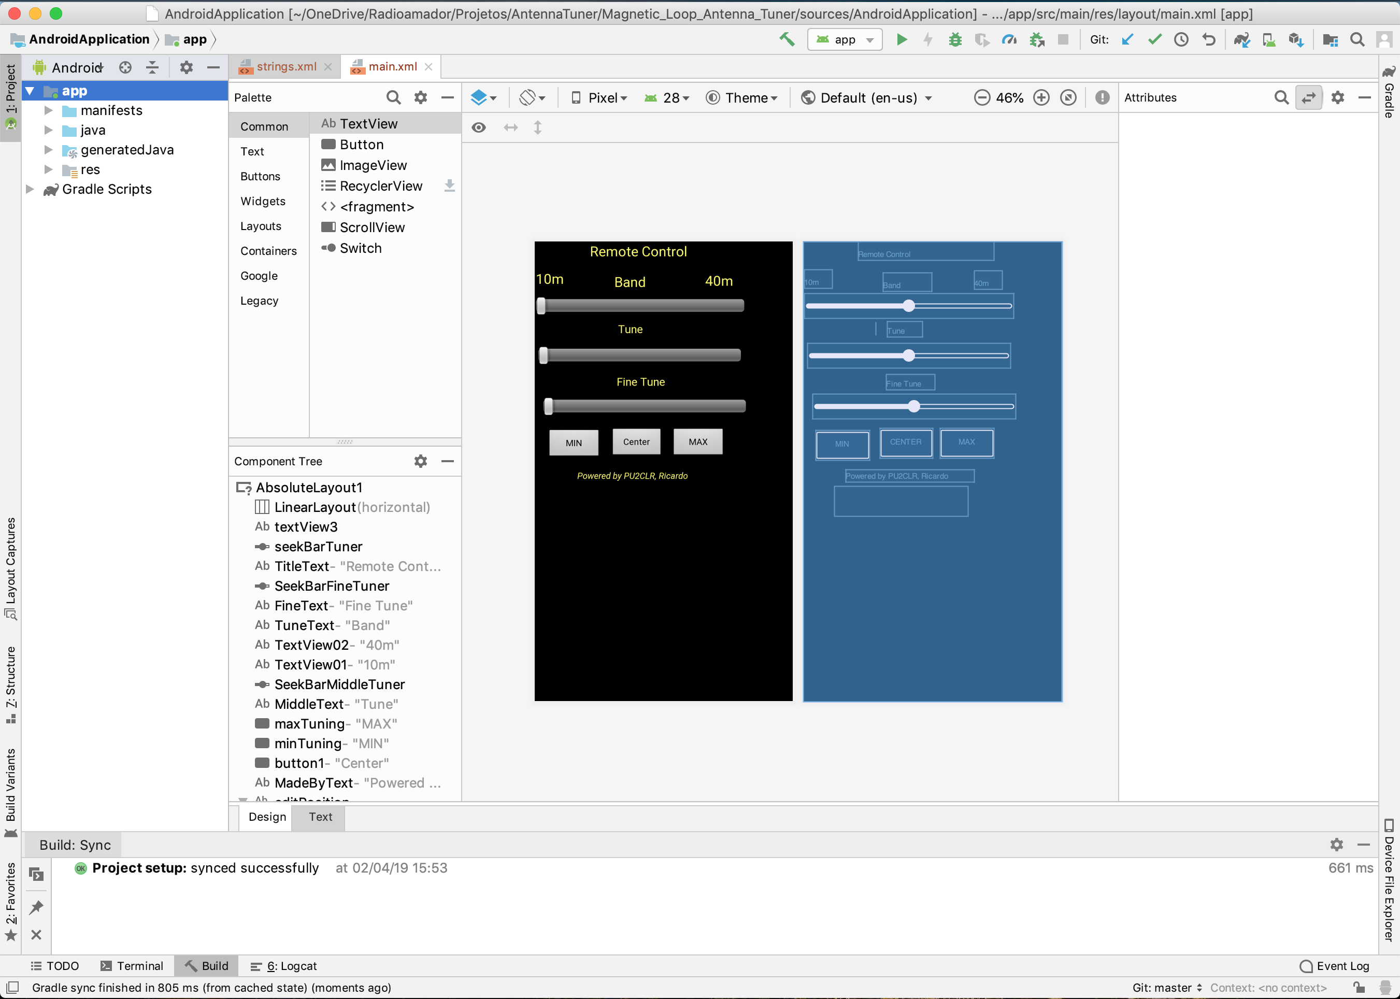
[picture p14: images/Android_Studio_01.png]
Android Studio


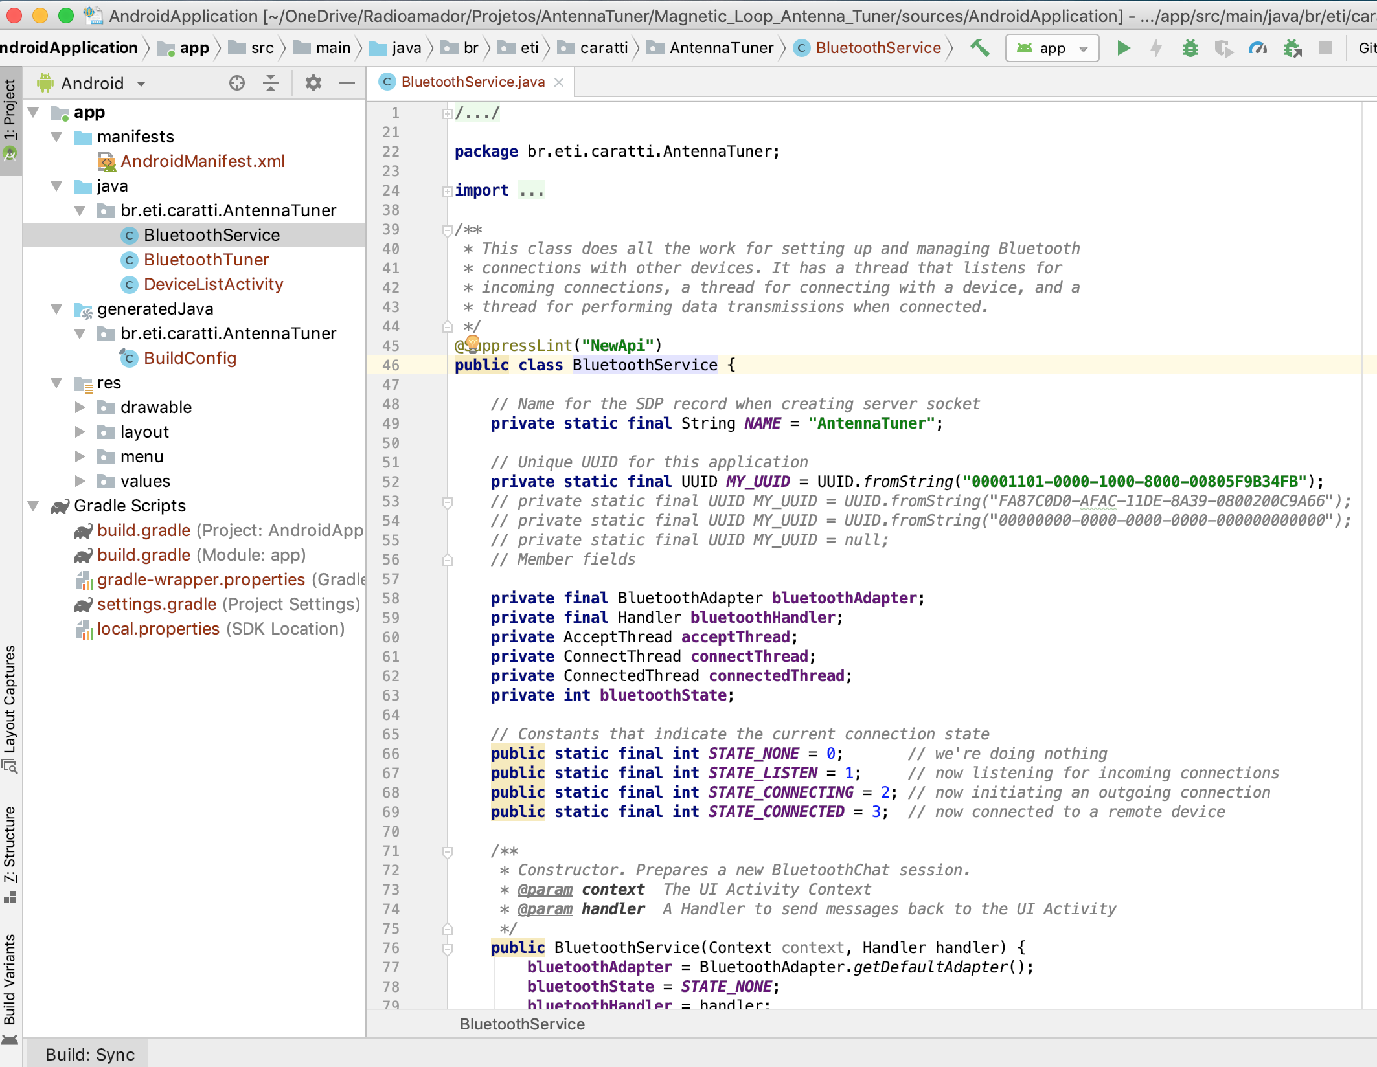
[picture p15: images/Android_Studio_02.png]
Android Studio


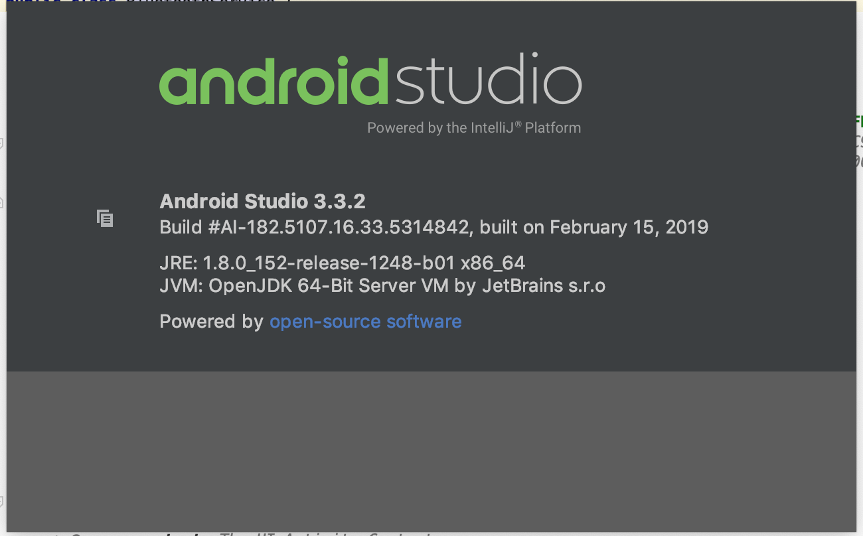
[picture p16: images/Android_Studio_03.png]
Android Studio


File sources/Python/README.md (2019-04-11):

#  Simple python program to test the Antenna Tuner Controller 

This Python program can be useful to test the communication of the Arduino prototype via Bluetooth.

If you are using an Unix system operator the Bluetooth / Serial connection be made as shown below.
```python
atu = serial.Serial(
port='/dev/tty.HC-05-DevB', 
        baudrate=9600,
        parity=serial.PARITY_ODD,
        stopbits=serial.STOPBITS_TWO,
        bytesize=serial.SEVENBITS
)
```
You should know what __/dev/tty*__ your bluetooth device is connected to your Unix computer.

If you are using Microsoft Windows the Bluetooth / Serial connection can be made as shown below.

```python
atu = serial.Serial(
        port='COM5',
        baudrate=9600,
        parity=serial.PARITY_ODD,
        stopbits=serial.STOPBITS_TWO,
        bytesize=serial.SEVENBITS
)
```

You should know what __COM*__ your bluetooth device is connected to your Windows computer.

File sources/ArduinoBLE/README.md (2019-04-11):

#  Arduino with  a HM10 (HMSoft) BLE

__So far, I could not develope a Mobile Application for Android and iOS to work with this magnetic antenna tunner. I'm still working on it.__ However, if you have a BLE device,  you can replace the HC-05 or similar to you BLE device. 
Istead of the Android Application developed for this project, you can use a regular Bluetooth Application like HM10 Bluetooth Serial for iOS or Serial Bluetooth Terminal for Android. With these application, you can control your tunner remotely. 

The photos below show the HM10 Bluetooth device (BLE), Android and iOS Aplications

## BLE (HM10 - HMSOft TineSine)

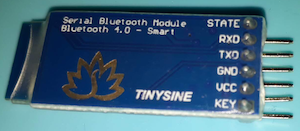
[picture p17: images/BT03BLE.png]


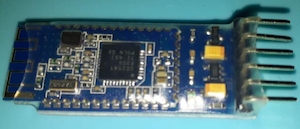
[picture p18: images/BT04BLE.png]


## HM10 Bluetooth Serial for iOS  (From Apple Store)

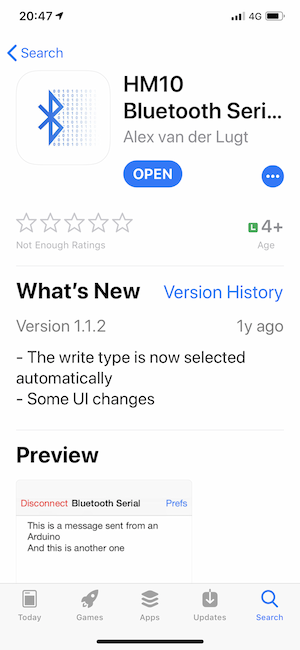
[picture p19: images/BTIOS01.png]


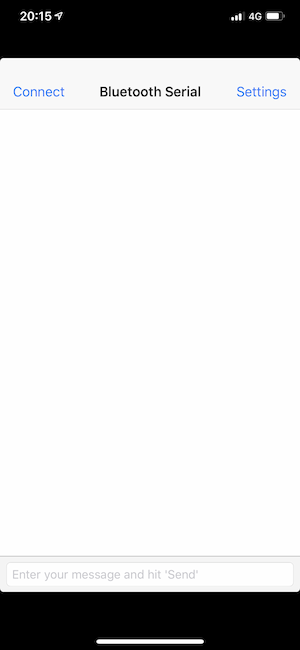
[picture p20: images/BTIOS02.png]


## Serial Bluetooth Terminal for Android (From Google Play)

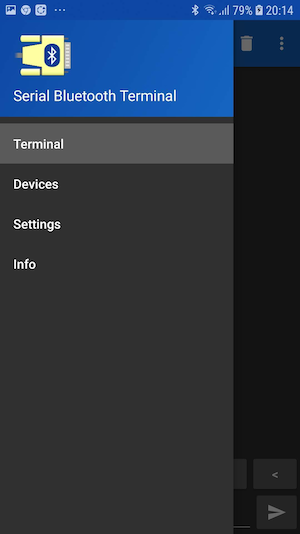
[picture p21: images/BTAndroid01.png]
Serial Bluetooth Terminal for Android


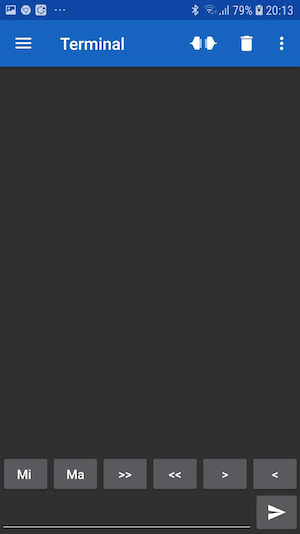
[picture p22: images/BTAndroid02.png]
Serial Bluetooth Terminal for Android


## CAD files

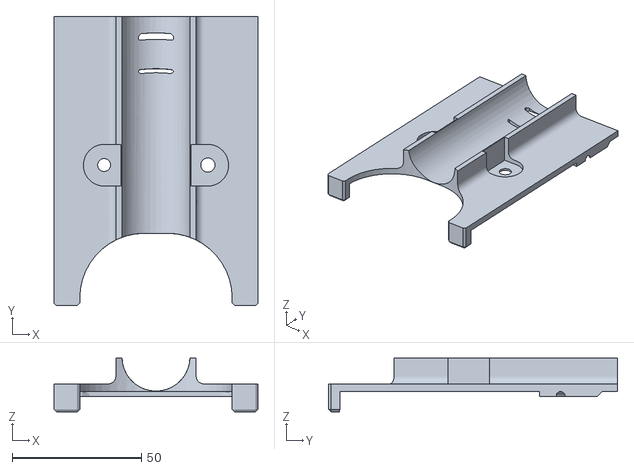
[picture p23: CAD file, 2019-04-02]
Box_3D_Printer/3D/Final/suporte.STL
79.0 x 112.0 x 20.9

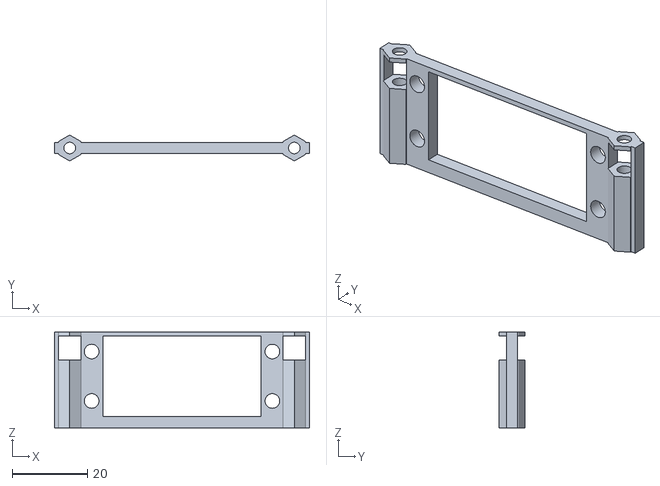
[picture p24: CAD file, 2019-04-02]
Box_3D_Printer/3D/Final_Version/gaveta_motores.STL
68.0 x 6.93 x 25.5

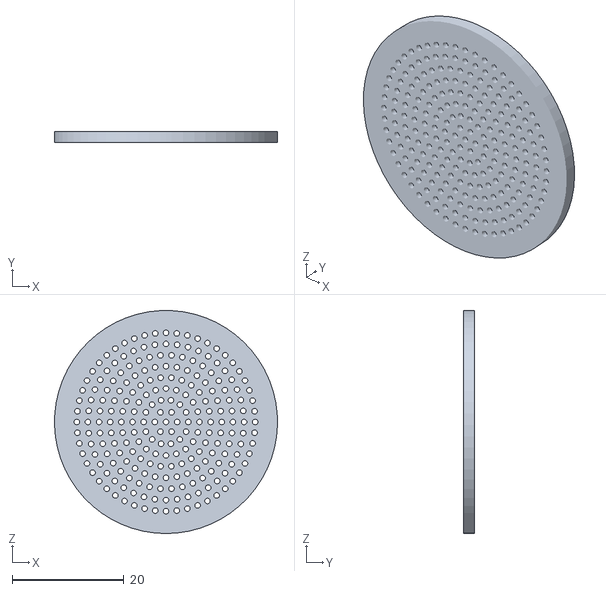
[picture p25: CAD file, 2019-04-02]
Box_3D_Printer/3D/Test_01/teste_1mm_2mm.STL
40.0 x 2.00 x 40.0

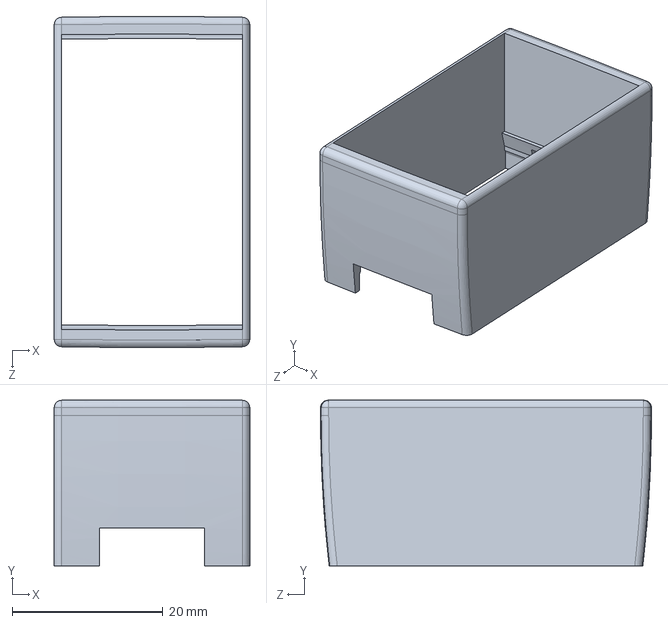
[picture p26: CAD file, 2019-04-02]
Box_3D_Printer/3D/Test_02/case-encaixe-teste.SLDPRT
26.0 x 22.0 x 44.0 mm

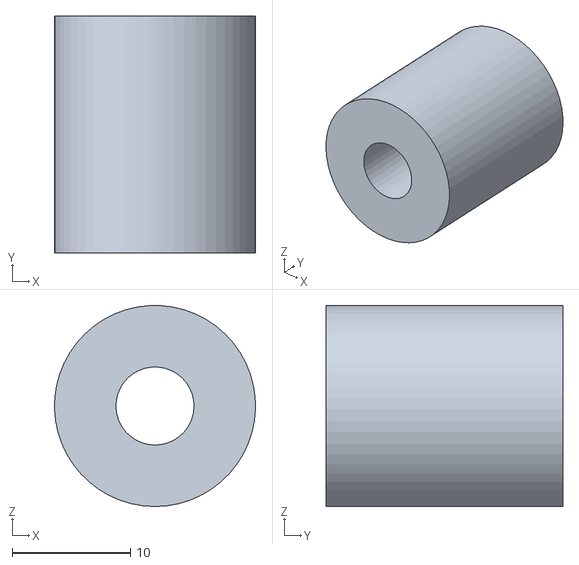
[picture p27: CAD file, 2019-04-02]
Box_3D_Printer/3D/Final/coupler-t.STL
17.0 x 20.0 x 17.0

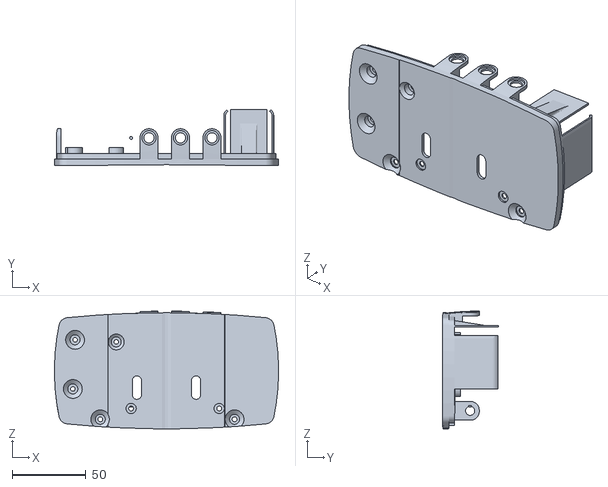
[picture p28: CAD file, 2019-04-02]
Box_3D_Printer/3D/Final_Version/base-20maio-final.STL
152.3 x 38.0 x 80.0

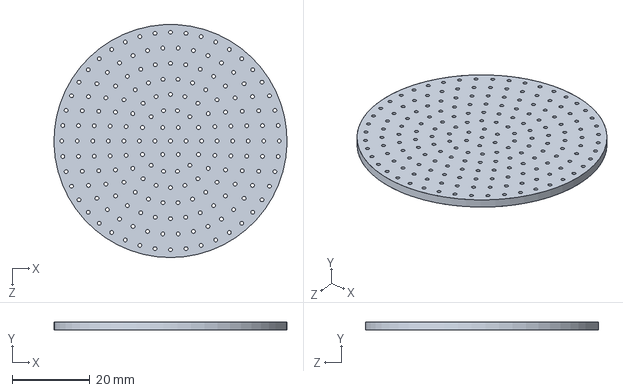
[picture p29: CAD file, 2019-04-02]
Box_3D_Printer/3D/Test_01/teste_1mm_4mm.SLDPRT
60.0 x 2.00 x 60.0 mm

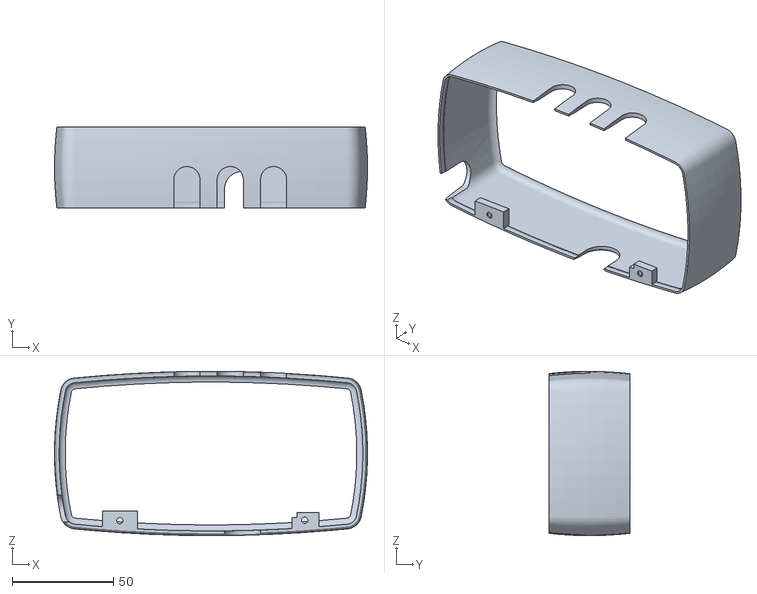
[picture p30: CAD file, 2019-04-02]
Box_3D_Printer/3D/Final/case-base.STL
154.6 x 40.0 x 81.2

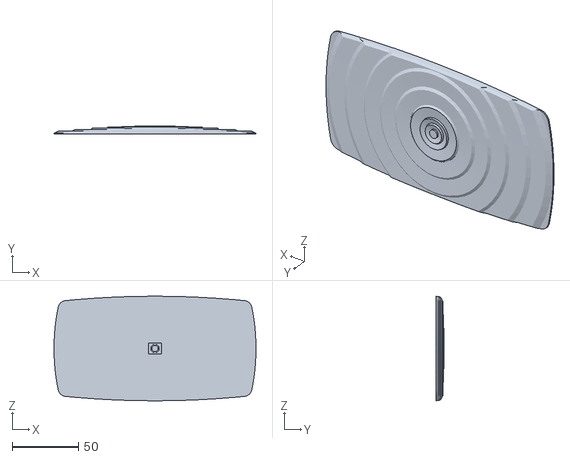
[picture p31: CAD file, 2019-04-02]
Box_3D_Printer/3D/Final_Version/ondas.STL
152.3 x 6.00 x 78.9

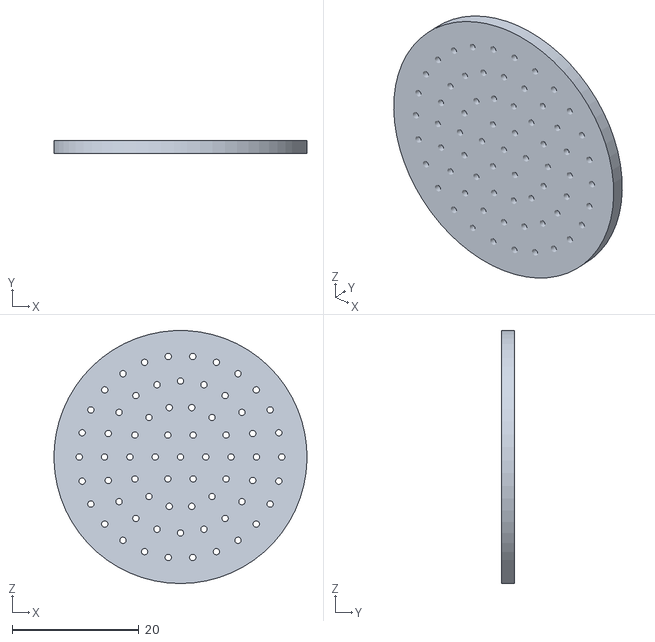
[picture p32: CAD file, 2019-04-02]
Box_3D_Printer/3D/Test_01/teste_2mm_4mm.STL
40.0 x 2.00 x 40.0

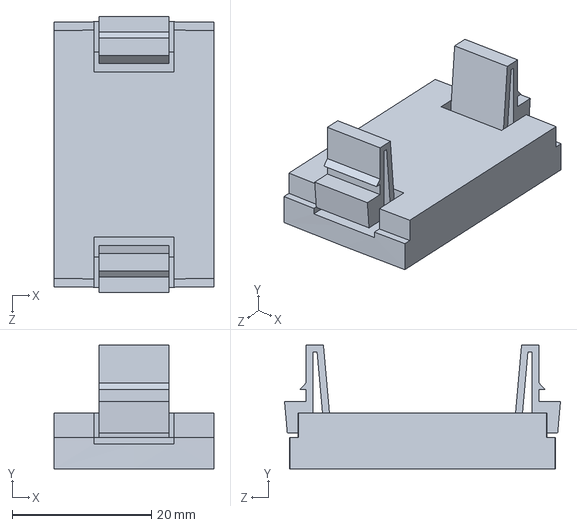
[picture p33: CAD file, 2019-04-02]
Box_3D_Printer/3D/Test_02/base-encaixe-teste.SLDPRT
22.9 x 17.7 x 39.6 mm

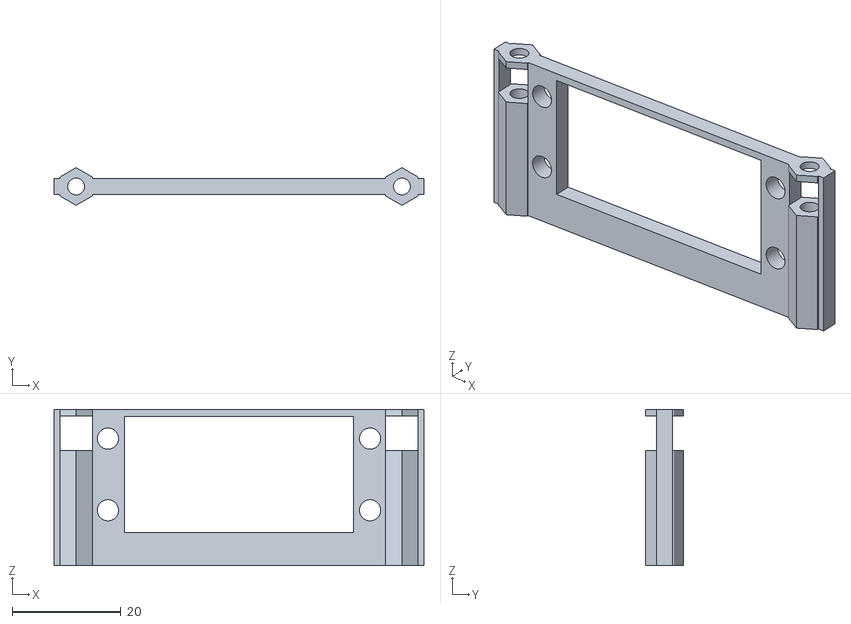
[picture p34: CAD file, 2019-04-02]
Box_3D_Printer/3D/Final/gaveta_motores.STL
68.0 x 6.93 x 28.7

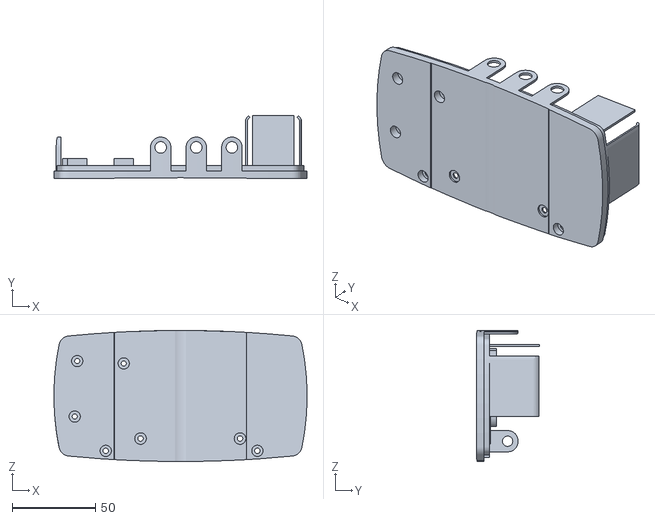
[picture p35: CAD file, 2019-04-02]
Box_3D_Printer/3D/Final_Version/base-09maio-final.STL
152.3 x 38.0 x 78.9

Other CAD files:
Box_3D_Printer/3D/Test_02/Untitled.FCStd
Box_3D_Printer/3D/Final/case-topo.STL
Box_3D_Printer/3D/Final_Version/suporte-final.STL
Box_3D_Printer/3D/Test_02/case_base_1.FCStd
Box_3D_Printer/3D/Final/base.STL
Box_3D_Printer/3D/Final_Version/base-07maio.STL
Box_3D_Printer/3D/Final_Version/base-08maio-final.STL
Box_3D_Printer/3D/Final_Version/base-11maio-final.STL
Box_3D_Printer/3D/Final_Version/base.STL
Box_3D_Printer/3D/Final_Version/cama.STL
Box_3D_Printer/3D/Final_Version/case-1.STL
Box_3D_Printer/3D/Final_Version/case-final08.STL
Box_3D_Printer/3D/Final_Version/case-lateral.STL
Box_3D_Printer/3D/Final_Version/case-topo.STL
Box_3D_Printer/3D/Final_Version/coupler.STL
Box_3D_Printer/3D/Final_Version/suporte.STL
Box_3D_Printer/3D/Test_01/teste_1mm_4mm.STL
Box_3D_Printer/3D/Test_02/base-encaixe-teste.STL
Box_3D_Printer/3D/Test_02/case-encaixe-teste.STL

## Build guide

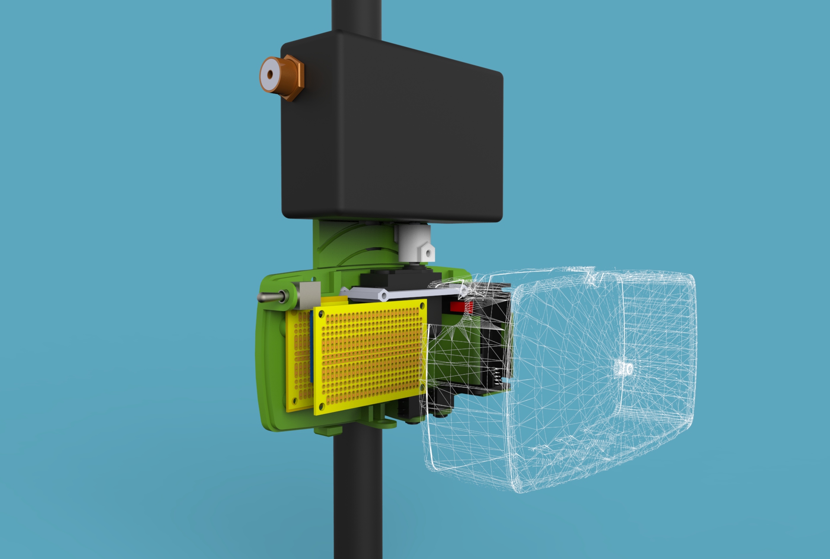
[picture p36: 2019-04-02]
Box_3D_Printer/Renderings/untitled.219.jpg

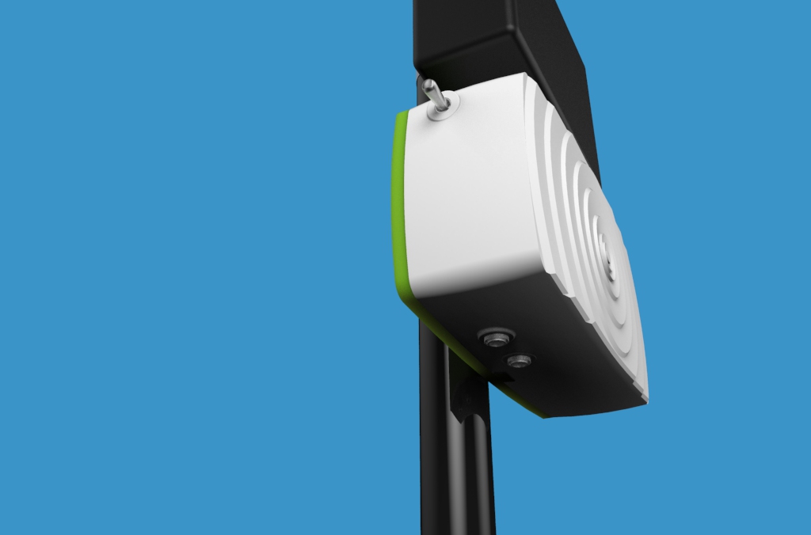
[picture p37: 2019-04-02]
Box_3D_Printer/Renderings/radioamador.17.jpg

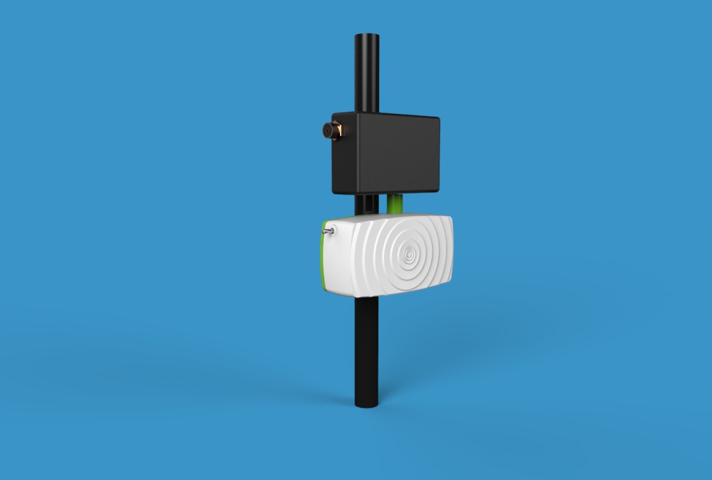
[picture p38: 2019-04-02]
Box_3D_Printer/Renderings/radioamador.15.jpg

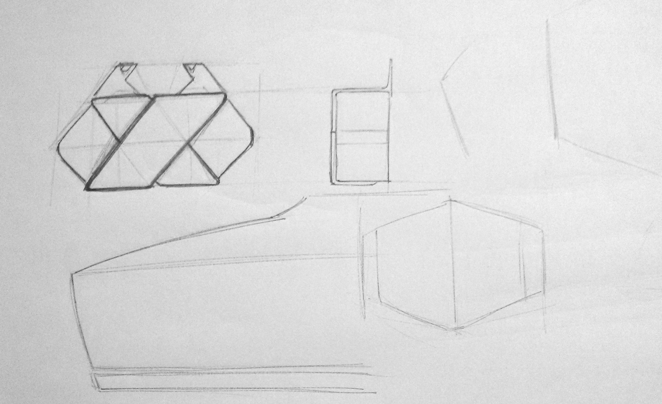
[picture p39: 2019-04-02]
Box_3D_Printer/Draft/4.png

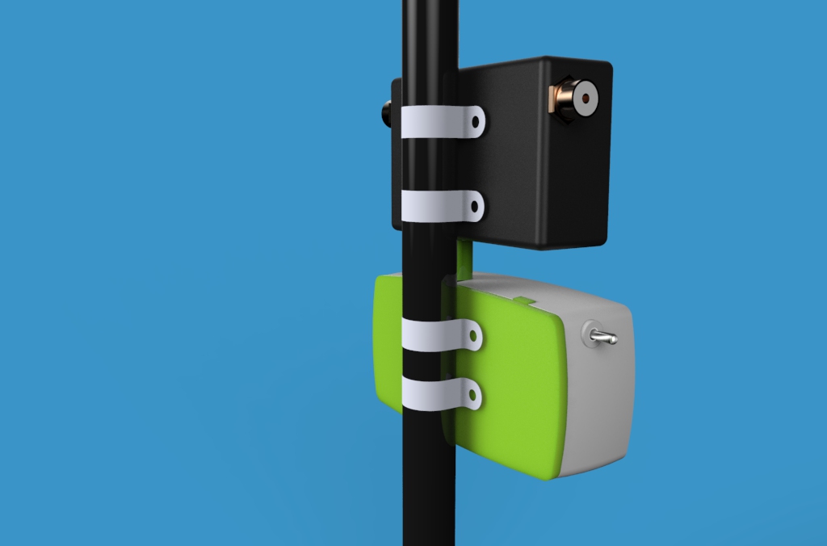
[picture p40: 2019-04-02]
Box_3D_Printer/Renderings/radioamador.18.jpg

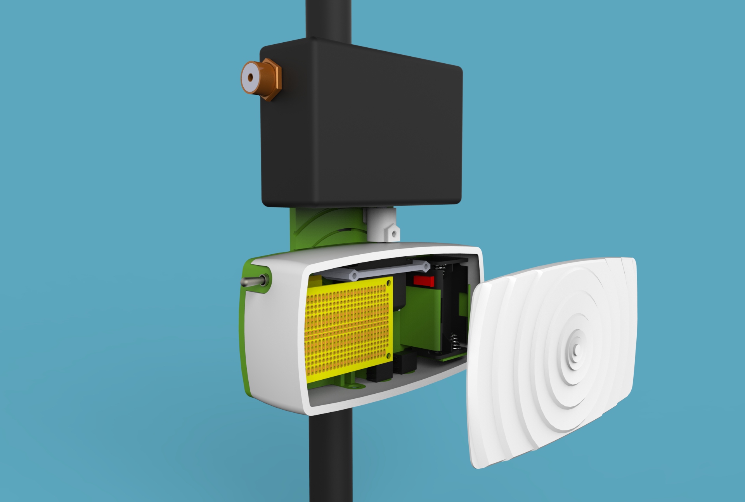
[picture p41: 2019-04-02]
Box_3D_Printer/Renderings/untitled.218.jpg

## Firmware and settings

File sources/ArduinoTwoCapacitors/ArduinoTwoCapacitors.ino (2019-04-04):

/*
** Antenna Tuner for Magnetic Loop
** Simplified version of Antenna Tuner with two capacitors
** By PU2CLR
** Ricardo Lima Caratti
** April 3th, 2019.
*/

#include <Servo.h>

// Capacitor classe. It can help you to use more then one capacitor (servos) on your project
class Capacitor {
  private:
    Servo servo;
    int _max;
    int _min;
    int _pos;
    int _pin;
    int _alert_led;

  protected:
    void blink(int pinLED, int times = 1, int timeslice = 15);

  public:
    Capacitor();
    initCapacitor(int, int, int, int);
    int move(int);
    int clockwise(int);
    int counterClockwise(int);
    void maxPos(void);
    void minPos(void);
    void center(void);
    int getPos();
};

Capacitor::Capacitor()
{

}
// Attach the Servo (Capacitor) and LED to Arduino. Also define the servo pulses limits;
Capacitor::initCapacitor(int pinCap, int pinLed, int minPulse, int maxPulse)
{
  _pin = pinCap;
  _alert_led = pinLed;
  _min = minPulse;
  _max = maxPulse;
  pinMode(_alert_led, OUTPUT);
  pinMode(_pin, OUTPUT);
  servo.attach(_pin, _min, _max);
}

// Move the capacitor to a position
int Capacitor::move(int pos) {
  if ( pos >= _min && pos <= _max ) {
    _pos = pos;
    servo.writeMicroseconds(pos);
    delay(8);
    return 1;
  }
  return 0;
}

// turn the capacitor clockwise n pulses
int Capacitor::clockwise(int pulse) {

  int tmp = pulse + _pos;

  blink(_alert_led);

  if ( tmp <= _max ) {
    _pos += pulse;
    servo.writeMicroseconds(_pos);
    delay(10);
    return 1;
  }
  blink(_alert_led, 5, 100);
  return 0;

}

// turn the capacitor counter-clockwise n pulses
int Capacitor::counterClockwise(int pulse) {

  int tmp = _pos - pulse;

  blink(_alert_led);

  if ( tmp >= _min ) {
    _pos -= pulse;
    servo.writeMicroseconds(_pos);
    delay(10);
    return 1;
  }
  blink(_alert_led, 5, 100);
  return 0;
}

// turn the capacitor to the max position
void Capacitor::maxPos() {
  _pos = _max;
  servo.writeMicroseconds(_max);
  blink(_alert_led, 3, 100);
}

// turn the capacitor to the min position
void Capacitor::minPos() {
  _pos = _min;
  servo.writeMicroseconds(_min);
  blink(_alert_led, 3, 100);
}

// get the position of the servo (Capacitor)
int Capacitor::getPos() {
  return _pos;
}

// turn the capacitor to the center position
void Capacitor::center() {
  _pos = _min + ( _max - _min) / 2;
  servo.writeMicroseconds( _pos );
}

// blink the led attached to the capacitor
void Capacitor::blink(int pinLED, int times, int timeslice) {

  int i;
  for ( i = 0; i < times; i++ ) {
    digitalWrite(pinLED, HIGH);
    delay(timeslice);
    digitalWrite(pinLED, LOW);
  }


}

// Define pulse width modulation for fine, regular and large tune
#define FINE_TUNE    5    // short pulse on servo
#define NORMAL_TUNE 15 // regular pulse on servo
#define LARGE_TUNE  50  // large pulse on servo


#define SERVO_MAINCAP_PIN     9          // Arduino pin where the main capacitor (Servo) is connected
#define SERVO_FINECAP_PIN    10          // Arduino pin where the fine tune  capacitor (Servo) is connected

#define CAP_LED_PIN         13            // Define the status LED pin of the capacitor

#define MIN_PULSE          800          // Min. pulse of the servo (you need to know abour you servo specification)
#define MAX_PULSE         2200          // Max. pulse of the servo (you need to know abour you servo specification)

Capacitor mainCap;   // Main capacitor
Capacitor fineCap;   // Fine tune capacitor 

void setup() {

     // Important: Dropout (disconnect) the Bluetooth from Arduino to upload this sketch to Arduino.
     Serial.begin(9600); // You have to know the speed of your bluetooth and set it up here. In this case it is 9600 bps

     // Attach the Capacitor to Servo and LED, and setup Servo parameters as well
     mainCap.initCapacitor(SERVO_MAINCAP_PIN, CAP_LED_PIN, MIN_PULSE, MAX_PULSE);
     fineCap.initCapacitor(SERVO_FINECAP_PIN, CAP_LED_PIN, MIN_PULSE, MAX_PULSE);

     // Show that the capacitors are alive.
     mainCap.maxPos();
     delay(200);
     mainCap.minPos();
     delay(200);
     mainCap.center();
     delay(200);
     mainCap.center();

     delay(1000);

     fineCap.maxPos();
     delay(200);
     fineCap.minPos();
     delay(200);
     fineCap.center();
     delay(200);
     fineCap.center();

     // The system is ready to be used.
     // Now you can connect this device to your Android mobile via Bluetooth
}


// Convert the message sent by the Android Application to pulses (position of the servo) 
long translatePosition() {
  int i = 0;
  char cnumero;
  char snumero[11];
  long valor_numerico;

  while ( (cnumero = Serial.read()) != '#' && i < 11) {
    if ( cnumero >= '0' && cnumero <= '9' ) {
      snumero[i++] = cnumero;
      Serial.flush();
    }
  }
  if (i >= 11 ) i = 10;
  snumero[i] = 0;
  return atol(snumero);
}


void loop() {

  int c;
  // Begin serial communication read process begins
  if (Serial.available()) {
    switch ( c =  Serial.read() ) {
      case '+':
      case '=':
        fineCap.clockwise(FINE_TUNE);
        break;
      case '-':
        fineCap.counterClockwise(FINE_TUNE);
        break;
      case 'r':
        mainCap.clockwise(NORMAL_TUNE);
        break;
      case 'l':
        mainCap.counterClockwise(NORMAL_TUNE);
        break;
      case 'R':
        mainCap.clockwise(LARGE_TUNE);
        break;
      case 'L':
        mainCap.counterClockwise(LARGE_TUNE);
        break;
      case 'M':
        mainCap.maxPos();
        delay(200);
        fineCap.maxPos();
        break;
      case 'm':
        mainCap.minPos();
        delay(200);
        fineCap.minPos();
        break;
      case 'C':
      case 'c':
        mainCap.center();
        delay(200);
        fineCap.center();
        break;
      case 'F':
        fineCap.move(translatePosition());
        break;
      case 'T':
        mainCap.move(translatePosition());
        break;
      default:
        Serial.flush();
        break;
    }

  }   // End serial read process

}
// End file (PU2CLR).

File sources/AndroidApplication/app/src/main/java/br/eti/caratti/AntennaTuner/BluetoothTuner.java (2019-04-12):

/*
 * Copyright (C) 2009 The Android Open Source Project
 *
 * Licensed under the Apache License, Version 2.0 (the "License");
 * you may not use this file except in compliance with the License.
 * You may obtain a copy of the License at
 *
 *      http://www.apache.org/licenses/LICENSE-2.0
 *
 * Unless required by applicable law or agreed to in writing, software
 * distributed under the License is distributed on an "AS IS" BASIS,
 * WITHOUT WARRANTIES OR CONDITIONS OF ANY KIND, either express or implied.
 * See the License for the specific language governing permissions and
 * limitations under the License.
 *
 * This code was an mConnectedThreadadaptation of BluetoothChat that came with Android SDK samples
 * This adaptation was made by Ricardo Lima Caratti, Ham radio, Callsign PU2CLR.
 * Brazil, 8/11/2012
 *
 *
 */

package br.eti.caratti.AntennaTuner;

// import com.example.android.BluetoothChat.R;

import android.annotation.SuppressLint;
import android.app.Activity;
import android.bluetooth.BluetoothAdapter;
import android.bluetooth.BluetoothDevice;
import android.content.Intent;
import android.os.Bundle;
import android.os.Handler;
import android.os.Message;
import android.view.Menu;
import android.view.MenuInflater;
import android.view.MenuItem;
import android.view.View;
import android.view.Window;
import android.widget.CheckBox;
import android.widget.EditText;
import android.widget.SeekBar;
import android.widget.SeekBar.OnSeekBarChangeListener;
import android.widget.TabHost;
import android.widget.TextView;
import android.widget.Toast;

/**
 * This Activity presents the Antenna Tuner controls .
 */
@SuppressLint("NewApi")
public class BluetoothTuner extends Activity implements OnSeekBarChangeListener {

    // Remote Control servo limits


    // Message types sent from the BluetoothChatService Handler
    public static final int MESSAGE_STATE_CHANGE = 1;
    public static final int MESSAGE_READ = 2;
    public static final int MESSAGE_WRITE = 3;
    public static final int MESSAGE_DEVICE_NAME = 4;
    public static final int MESSAGE_TOAST = 5;

    // Key names received from the BluetoothChatService Handler
    public static final String DEVICE_NAME = "device_name";
    public static final String TOAST = "toast";

    // Intent request codes
    private static final int REQUEST_CONNECT_DEVICE = 1;
    private static final int REQUEST_ENABLE_BT = 2;

    // Layout Views
    private TextView titleApp;
    // Name of the connected device
    private String connectedDeviceName = null;

    private EditText feedBackPosition;

    // Local Bluetooth adapter
    private BluetoothAdapter bluetoothAdapter = null;
    // Member object for the chat services
    private BluetoothService tunerService = null;

    TabHost tabHost;

    // ATU commands
    private SeekBar seekbarTune;
    private SeekBar seekbarMiddleTune;
    private SeekBar seekbarFineTune;
    private int seekPos = 0;

    private CheckBox twoCapacitorsCheckbox;

    // You might change this setup depending on your servo specification
    public int OFFSET = 800;   // Min. Pisition  (0 degree)
    public int MAXPOS = 2200;  // Max. position  (Max. degrre)
    public int CENTER = (MAXPOS - OFFSET)/2 + OFFSET /2;   // Center is CENTER + OFFSET


    // IMPORTANT
    // If you are using two capacitors version (with low capacitance device), you might change the
    // values on onTwoCapacitorsClicked.

    // One capacitor version for regular tune
    public int MIDDLE_MAX_OFFSET;
    public int MIDDLE_CENTER;

    // One capacitor version  for fine tune
    public int FINE_MAX_OFFSET;
    public int FINE_CENTER;


    @Override
    public void onCreate(Bundle savedInstanceState) {
        super.onCreate(savedInstanceState);

        // Assume one capacitor at first estimated parameters
        // See onTwoCapacitorsClicked if you are using Two Capacitors version.
        MIDDLE_MAX_OFFSET = MAXPOS / 4;
        MIDDLE_CENTER = CENTER / 4;
        FINE_MAX_OFFSET = MAXPOS / 8;
        FINE_CENTER = CENTER / 8;



        // Set up the window layout
        requestWindowFeature(Window.FEATURE_CUSTOM_TITLE);
        setContentView(R.layout.main);
        getWindow().setFeatureInt(Window.FEATURE_CUSTOM_TITLE,
                R.layout.custom_title);

        // Set up the custom title
        titleApp = (TextView) findViewById(R.id.title_left_text);
        titleApp.setText(R.string.app_name);
        titleApp = (TextView) findViewById(R.id.title_right_text);

        seekbarTune = (SeekBar) findViewById(R.id.seekBarTuner);
        seekbarTune.setMax(MAXPOS);
        seekbarTune.setProgress(CENTER);
        seekbarTune.setOnSeekBarChangeListener((OnSeekBarChangeListener) this);

        seekbarMiddleTune = (SeekBar) findViewById(R.id.SeekBarMiddleTuner);
        seekbarMiddleTune.setMax(MIDDLE_MAX_OFFSET);
        seekbarMiddleTune.setProgress(MIDDLE_CENTER);
        seekbarMiddleTune.setOnSeekBarChangeListener((OnSeekBarChangeListener) this);


        seekbarFineTune = (SeekBar) findViewById(R.id.SeekBarFineTuner);
        seekbarFineTune.setMax(FINE_MAX_OFFSET);
        seekbarFineTune.setProgress(FINE_CENTER);

        seekbarFineTune.setOnSeekBarChangeListener((OnSeekBarChangeListener) this);

        twoCapacitorsCheckbox = (CheckBox) findViewById(R.id.twoCapacitors);
        twoCapacitorsCheckbox.setChecked(false);


        // Get local Bluetooth adapter
        bluetoothAdapter = BluetoothAdapter.getDefaultAdapter();


        feedBackPosition = (EditText) findViewById(R.id.editPosition);
        feedBackPosition.setEnabled(false);
        feedBackPosition.setFocusable(false);

        // If the adapter is null, then Bluetooth is not supported
        if (bluetoothAdapter == null) {
            Toast.makeText(this, "Bluetooth is not available",
                    Toast.LENGTH_LONG).show();
            finish();
            return;
        }

    }

    @Override
    public void onStart() {
        super.onStart();

        if (!bluetoothAdapter.isEnabled()) {
            Intent enableIntent = new Intent(
                    BluetoothAdapter.ACTION_REQUEST_ENABLE);
            startActivityForResult(enableIntent, REQUEST_ENABLE_BT);
            // Otherwise, setup the chat session
        } else {
            if (tunerService == null)
                setupTuner();
        }
    }

    @Override
    public synchronized void onResume() {
        super.onResume();
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

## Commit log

2019-04-02 First Upload
    [minimalist_schematic.fzz]
2019-04-02 One Capacitor Android App
2019-04-03 Arduino sketch
2019-05-01 Arduino BLE Stetch
2019-05-01 Arduino BLE sketch
2019-05-01 BLE HM10 Arduino Sketch
